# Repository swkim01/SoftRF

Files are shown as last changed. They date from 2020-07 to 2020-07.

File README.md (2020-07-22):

# SoftRF &nbsp;&nbsp;&nbsp;&nbsp;&nbsp;   
Multifunctional DIY IoT-based general aviation proximity awareness system.

Features:
* 2-way raw data bridge between 868/915 MHz radio band and Wi-Fi ;
* standalone, battery powered, compatible proximity awareness instrument that fits typical 2.25 inches hole ;
* lightweight version to carry onboard of an UAV.

# Compatibility <sup>1</sup>
Type|Protocol|FLARM|OGN tracker|PilotAware|Skytraxx|SoftRF
---|---|---|---|---|---|---
Radio|FLARM AIR V6||||<p align="center"><sup>2</sup></p>|
&nbsp;|<p align="center">OGNTP</p>|||||<p align="center"><sup>3</sup></p>
&nbsp;|<p align="center">P3I</p>|||||<p align="center"><sup>3</sup></p>
&nbsp;|<p align="center">UAT&nbsp;978</p>|||||<p align="center"><sup>4</sup></p>
&nbsp;|<p align="center">FANET+</p>|||||<p align="center"><sup>3</sup></p>
Data|FLARM NMEA|||||
&nbsp;|Garmin GDL90|||||
&nbsp;|<p align="center">MAVLINK</p>|||||
&nbsp;|<p align="center">Dump1090 &nbsp;<sup>5</sup></p>|||||

<sup>1</sup> - it is necessary for a reader to distinguish the difference between statement "**compatible**" and statement "**fully compatible**".<br>
&nbsp;&nbsp;&nbsp;&nbsp; SoftRF implements only a reasonable minimum of the protocols specs. No "bells and whistles" so far.<br>
<sup>2</sup> - FANET+ can not receive FLARM. However it is able to transmit it.<br>
<sup>3</sup> - valid for [**Prime Mark II**](https://github.com/lyusupov/SoftRF/wiki/Prime-Edition-MkII) and [**Dongle**](https://github.com/lyusupov/SoftRF/wiki/Dongle-Edition) **Editions**; valid for **Standalone** and **UAV** **Editions** with optional DIY [SoftRF LoRa RF module](https://github.com/lyusupov/SoftRF/wiki/SoftRF-LoRa-module)<br>
<sup>4</sup> - [**Reception**](https://github.com/lyusupov/SoftRF/tree/master/software/firmware/source/UATbridge) of traffic 'downlink' frames only. Valid for **Standalone Edition** with optional DIY [SoftRF UAT module](https://github.com/lyusupov/UAT-test-signal#variant-2-advanced)<br>
<sup>5</sup> - also known as "raw ADS-B"<br>

# Models
Model|Platform|First appearance|&nbsp;&nbsp;&nbsp;&nbsp;&nbsp;&nbsp;&nbsp;Status&nbsp;&nbsp;&nbsp;&nbsp;&nbsp;&nbsp;&nbsp;|Comment
---|:---:|:---:|:---:|---
1&nbsp;[Prime](https://github.com/lyusupov/SoftRF/wiki/Prime-Edition)<br>2&nbsp;[Standalone](https://github.com/lyusupov/SoftRF/wiki/Standalone-Edition)<br>3&nbsp;[UAV](https://github.com/lyusupov/SoftRF/wiki/UAV-Edition)<br>4&nbsp;[**WebTop**](https://github.com/lyusupov/SoftRF/wiki/WebTop-WiFi-adapter)|[Espressif<br>ESP8266](https://en.wikipedia.org/wiki/ESP8266)|Q4 2015||[Prime](https://github.com/lyusupov/SoftRF/wiki/Prime-Edition) model is no longer supported - use [Prime MkII](https://github.com/lyusupov/SoftRF/wiki/Prime-Edition-MkII) instead.<br><!-- ESP8266 platform will be phased out through year 2020 in favour of ESP32.-->
1&nbsp;[**Prime Mark II**](https://github.com/lyusupov/SoftRF/wiki/Prime-Edition-MkII)<br>2&nbsp;[**Standalone**](https://github.com/lyusupov/SoftRF/wiki/Standalone-Edition) + [adapter](https://github.com/lyusupov/ESP32-NODEMCU-ADAPTER)<br>3&nbsp;[UAV](https://github.com/lyusupov/SoftRF/wiki/UAV-Edition)<br>4&nbsp;[**SkyView EZ**](https://github.com/lyusupov/SoftRF/wiki/SkyView-EZ)<br>5&nbsp;[Flight Recorder](https://github.com/lyusupov/SoftRF/wiki/Flight-Recorder)|[Espressif<br>ESP32](https://en.wikipedia.org/wiki/ESP32)|Q1 2018||Today's best platform
1&nbsp;[**Raspberry Edition**](https://github.com/lyusupov/SoftRF/wiki/Raspberry-Edition)<br>2&nbsp;[**SkyView Pi**](https://github.com/lyusupov/SoftRF/wiki/SkyView-Pi)|[Broadcom<br>BCM283X<br>(Raspberry Pi)](https://en.wikipedia.org/wiki/Raspberry_Pi)|Q4 2018||Good for use together with RTL-SDR dongles to achieve additional 1090ES (and 978UAT) ADS-B air traffic reception.
1&nbsp;[UAT module](https://github.com/lyusupov/UAT-test-signal#variant-2-advanced)<br>2&nbsp;**Uni**|[Texas Instruments<br>CC1310](http://www.ti.com/product/CC1310) and [CC1352](http://www.ti.com/product/CC1352R)|Q1 2019|<!-- ![](https://placehold.it/140x40/c5f015/000000?text=May+need)<br>![](https://placehold.it/140x40/c5f015/000000?text=improvements) --> <!-- ![](https://placehold.it/140x70/FFFF00/000000?text=In+progress) -->|Unique RF radio specs are useful for [UAT reception](https://github.com/lyusupov/SoftRF/tree/master/software/firmware/source/UATbridge) [ [1](https://raw.githubusercontent.com/lyusupov/SoftRF/master/documents/images/uat-normal-7.jpg) , [2](https://raw.githubusercontent.com/lyusupov/SoftRF/master/documents/images/uat-normal-8.jpg) , [3](https://raw.githubusercontent.com/lyusupov/SoftRF/master/documents/images/uat-normal-6.jpg) ].
1&nbsp;[**Dongle**](https://github.com/lyusupov/SoftRF/wiki/Dongle-Edition)<br>2&nbsp;[Retro](https://github.com/lyusupov/SoftRF/wiki/Retro-Edition)|[STMicroelectronics<br>STM32](https://en.wikipedia.org/wiki/STM32)|Q3 2019|<!-- ![](https://placehold.it/140x70/FFFF00/000000?text=In+progress)-->|[AcSiP **S76G**](http://www.acsip.com.tw/index.php?action=products-detail&fid1=19&fid2=&fid3=&id=41&lang=3) "3-in-1" system-in-package **is doing good** [ [1](https://raw.githubusercontent.com/lyusupov/SoftRF/master/documents/images/watch-1.jpg) , [2](https://raw.githubusercontent.com/lyusupov/SoftRF/master/documents/images/t-motion-4.jpg) , [3](https://raw.githubusercontent.com/lyusupov/SoftRF/master/documents/images/t-motion-5.jpg) ] .<br>As well as STM32F103C8 "**Blue Pill**" (same MCU that [STM32 OGN tracker](http://wiki.glidernet.org/stm32-ogn-tracker) uses) [ [4](https://raw.githubusercontent.com/lyusupov/SoftRF/master/documents/images/stm32_breadboard.jpg) , [5](https://raw.githubusercontent.com/lyusupov/SoftRF/master/documents/images/stm32_ognweb_1.JPG) ] .

# Documentation

* SoftRF overview
    * [Part 1](https://github.com/lyusupov/SoftRF/blob/master/documents/SoftRF-release-1.pdf) (PDF, December 2015)
    * [Part 2](https://github.com/lyusupov/SoftRF/raw/master/documents/SoftRF-release-2.pdf) (PDF, March 2017)
* [Prime Edition MkII](https://github.com/lyusupov/SoftRF/wiki/Prime-Edition-MkII) 
    * [Quick start](https://github.com/lyusupov/SoftRF/wiki/Prime-Edition-MkII.-Quick-start)
    * [Enclosure](https://github.com/lyusupov/SoftRF/tree/master/case/v5)
* [Standalone Edition](https://github.com/lyusupov/SoftRF/wiki/Standalone-Edition)
    * [Specifications](https://github.com/lyusupov/SoftRF/wiki/Standalone-Specifications)
    * [Shield](https://github.com/lyusupov/SoftRF/wiki/Standalone-Shield)
    * [Modules](https://github.com/lyusupov/SoftRF/wiki/Standalone-Modules)
    * [Assembly](https://github.com/lyusupov/SoftRF/tree/master/hardware)
    * [Enclosure](https://github.com/lyusupov/SoftRF/tree/master/case/v4)
    * [ESP32 adapter](https://github.com/lyusupov/ESP32-NODEMCU-ADAPTER)
* [Dongle Edition](https://github.com/lyusupov/SoftRF/wiki/Dongle-Edition) 
    * [Firmware installation](https://github.com/lyusupov/SoftRF/wiki/AcSiP-S7xG-flashing-instructions)
    * [Quick start](https://github.com/lyusupov/SoftRF/wiki/Dongle-Edition.-Quick-start)
    * [Settings](https://github.com/lyusupov/SoftRF/wiki/Dongle-settings)
    * [Enclosure](https://github.com/lyusupov/SoftRF/tree/master/case/Dongle)
* [UAV Edition](https://github.com/lyusupov/SoftRF/wiki/UAV-Edition)
    * [Bill of materials](https://github.com/lyusupov/SoftRF/wiki/UAV-BOM)
    * [Wiring and pin-out](https://github.com/lyusupov/ESP32-NODEMCU-ADAPTER)
    * [Enclosure](https://github.com/lyusupov/SoftRF/tree/master/case/UAV)
* [Raspberry Edition](https://github.com/lyusupov/SoftRF/wiki/Raspberry-Edition) 
* [Retro Edition](https://github.com/lyusupov/SoftRF/wiki/Retro-Edition)

* SkyView
    * [EZ](https://github.com/lyusupov/SoftRF/wiki/SkyView-EZ) 
        * [Quick start](https://github.com/lyusupov/SoftRF/wiki/SkyView.-Quick-start)
        * [Settings](https://github.com/lyusupov/SoftRF/wiki/SkyView-settings)
        * [Enclosure](https://github.com/lyusupov/SoftRF/tree/master/case/SkyView)
        * [Dual boot](https://github.com/lyusupov/SoftRF/wiki/SkyView.-Dual-boot) 
    * [Pi](https://github.com/lyusupov/SoftRF/wiki/SkyView-Pi) 
* [WebTop](https://github.com/lyusupov/SoftRF/wiki/WebTop-WiFi-adapter) 

* [Flight Recorder](https://github.com/lyusupov/SoftRF/wiki/Flight-Recorder)
    * [Quick start](https://github.com/lyusupov/SoftRF/wiki/Flight-Recorder.-Quick-Start)

* Software
    * Firmware
        * [Release information](https://github.com/lyusupov/SoftRF/releases) 
        * [Binary](https://github.com/lyusupov/SoftRF/tree/master/software/firmware/binaries)
        * [Settings](https://github.com/lyusupov/SoftRF/wiki/Settings)
        * [Update](https://github.com/lyusupov/SoftRF/wiki/Firmware-update-(Web-method)) (Web method)
        * [Source](https://github.com/lyusupov/SoftRF/tree/master/software/firmware/source)
* Extras
    * [Long range (LoRa) RF module](https://github.com/lyusupov/SoftRF/wiki/SoftRF-LoRa-module)
    * Protocols
        * [UAT](https://github.com/lyusupov/SoftRF/tree/master/software/firmware/source/UATbridge)    
        * [OGNTP](https://github.com/lyusupov/SoftRF/wiki/OGNTP-compatibility)
        * [P3I Open (PilotAware)](https://github.com/lyusupov/SoftRF/wiki/PilotAware-compatibility)
        * [FANET (Skytraxx)](https://github.com/lyusupov/SoftRF/wiki/FANET-compatibility)
    * [Garmin GDL90 datalink](https://github.com/lyusupov/SoftRF/wiki/Garmin-GDL90-compatibility)
        * [SkyDemon](https://github.com/lyusupov/SoftRF/wiki/Garmin-GDL90-compatibility#skydemon)
        * [Avare](https://github.com/lyusupov/SoftRF/wiki/Garmin-GDL90-compatibility#avare)
        * [ForeFlight](https://github.com/lyusupov/SoftRF/wiki/Garmin-GDL90-compatibility#foreflight)
    * [Integration with airborne (Stratux, PilotAware,...) and groundstation (FlightRadar24, FlightAware,...) ADS-B receivers](https://github.com/lyusupov/SoftRF/wiki/Integration-with-RTL%E2%80%90SDR-based-ADS%E2%80%90B-receivers)
    * [Combined use of multiple SoftRF units](https://github.com/lyusupov/SoftRF/tree/master/software/app/XCSoar7_preview12_plus)
* Archive
    * [Prime Edition](https://github.com/lyusupov/SoftRF/wiki/Prime-Edition)
        * [Bill of materials](https://github.com/lyusupov/SoftRF/wiki/Prime-BOM)
        * [Wiring](https://github.com/lyusupov/SoftRF/wiki/Prime-Wiring)
        * [Enclosure](https://github.com/lyusupov/SoftRF/tree/master/case/v1)
    * Applications
        * [Emulator](https://github.com/lyusupov/SoftRF/tree/master/software/app/Emulator)

# Highlights

* [**Prime Edition Mark II**](https://github.com/lyusupov/SoftRF/wiki/Prime-Edition-MkII)



* [**Standalone Edition**](https://github.com/lyusupov/SoftRF/wiki/Standalone-Edition)





* [**Dongle Edition**](https://github.com/lyusupov/SoftRF/wiki/Dongle-Edition)

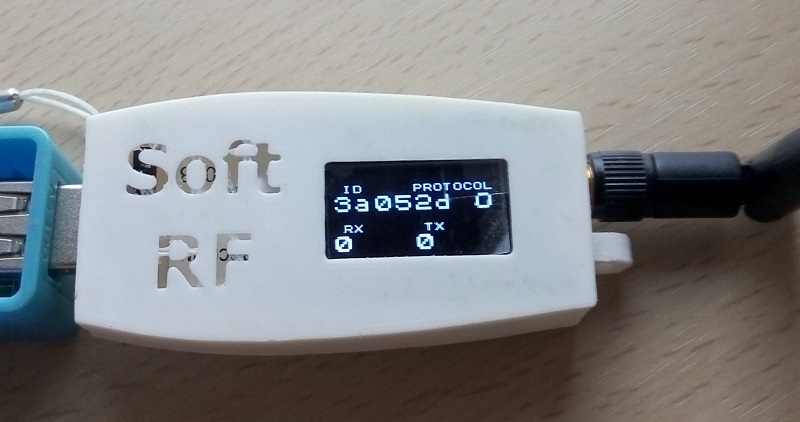
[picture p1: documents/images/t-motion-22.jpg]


* [**SkyView EZ**](https://github.com/lyusupov/SoftRF/wiki/SkyView-EZ)



* [**UAV appliance**](https://github.com/lyusupov/SoftRF/wiki/UAV-Edition)



* [**Flight Recorder**](https://github.com/lyusupov/SoftRF/wiki/Flight-Recorder)

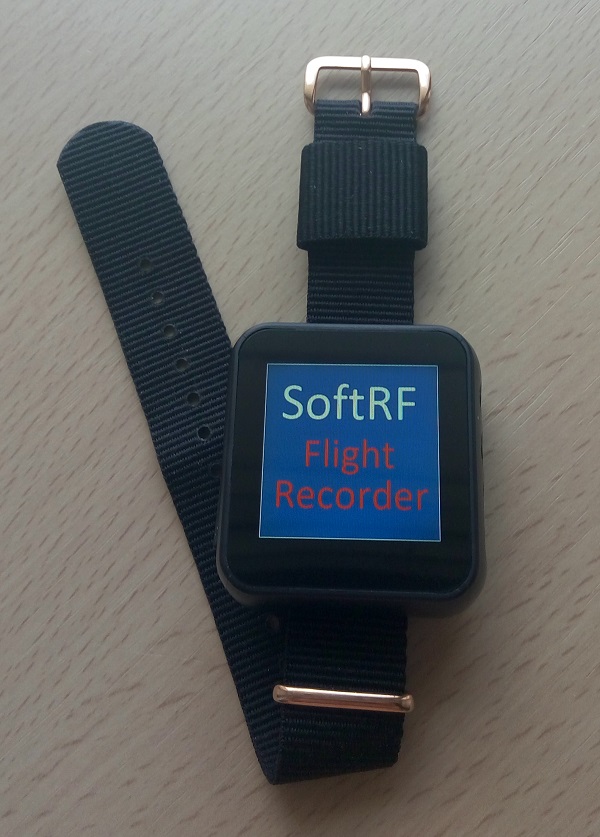
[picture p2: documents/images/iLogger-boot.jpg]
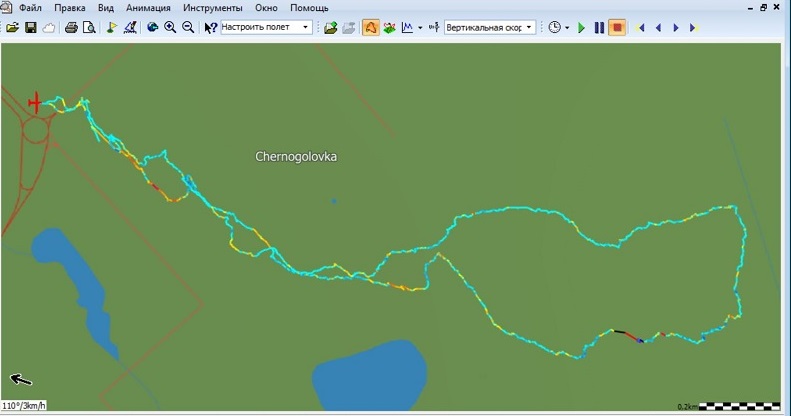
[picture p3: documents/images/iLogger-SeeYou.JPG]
<p>&nbsp;</p>

<!--
* [**Software driven emulation**](https://github.com/lyusupov/SoftRF/wiki/Prime-Edition)

![](https://github.com/lyusupov/SoftRF/raw/master/documents/images/softrf-emulation.jpg)

![](https://github.com/lyusupov/SoftRF/raw/master/documents/images/LK8000-emu.jpg)

![](https://github.com/lyusupov/SoftRF/blob/master/case/v1/SoftRF-Case-v1-Exterior.jpg)
-->

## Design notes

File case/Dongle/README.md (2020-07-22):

# Dongle enclosure 

This type of enclosure is built around LilyGO&#174; & SoftRF [**T-Motion**](https://github.com/lyusupov/SoftRF/wiki/Dongle-Edition#required) LoRaWAN GNSS tracker board.<br>

**NOTICE**: This design is applicable for revision V1.1 (pre-production sample) of the T-Motion. Other revisions may or may not match.

# Exterior

It is recommended to start with 'Slim' variant of the design.<br>
It has almost no space for 'extras'. However it gives an access to the board pin headers and BOOT button.<br>

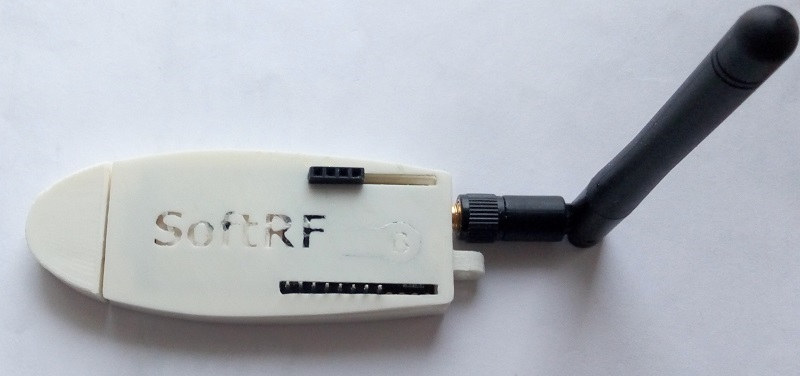
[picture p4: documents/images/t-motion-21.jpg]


<br>

There is an alternative design for the lid of this enclosure to fit for [0.96" OLED I<sup>2</sup>C display](https://www.aliexpress.com/item/32922106384.html)<br>



<br>

and an alternative design for main 'body' to give some space for:

- [402030 Li-Ion battery](https://www.aliexpress.com/item/32909694329.html) and/or
- [I<sup>2</sup>C BMP280 barometric pressure sensor](https://www.aliexpress.com/item/32680504702.html).

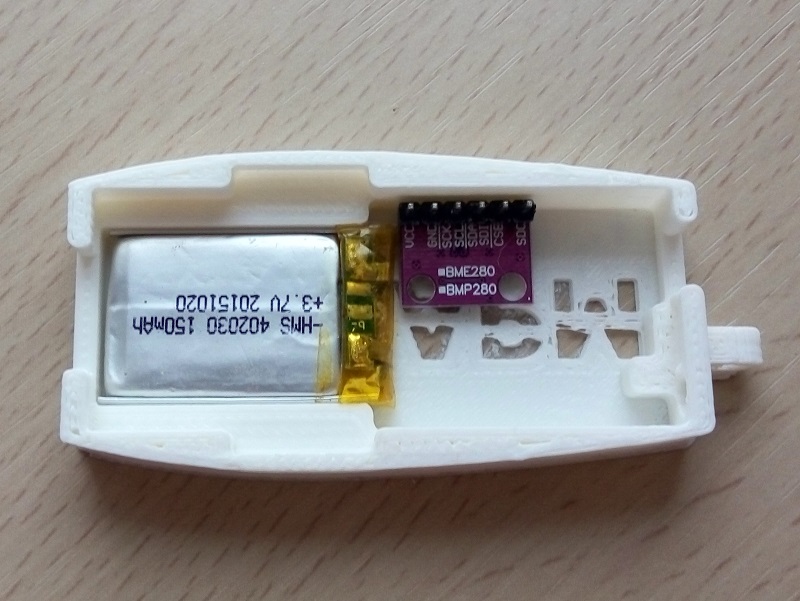
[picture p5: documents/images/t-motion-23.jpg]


<br>

# Instructions

3D print three STL files from this folder: **Body**, **Lid** and **Cap**. You may pick some printing advisories on [my Thingiverse page](https://www.thingiverse.com/thing:4033445).<br>
If you are unable to print the parts by yourself - you may consider to find an appropriate local 3D service provider and place an order with assistance of [Treatstock](http://www.treatstock.com) or [3DHubs](http://www.3dhubs.com/) portals.

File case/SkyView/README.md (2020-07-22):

# SkyView enclosure 

This type of enclosure is built around [TTGO T5S](http://s.click.aliexpress.com/e/Zp4ygfQ) board.<br>

**NOTICE**: This design is applicable for revision V1.9 of T5S. Other revisions may not match.

# Exterior

<p>
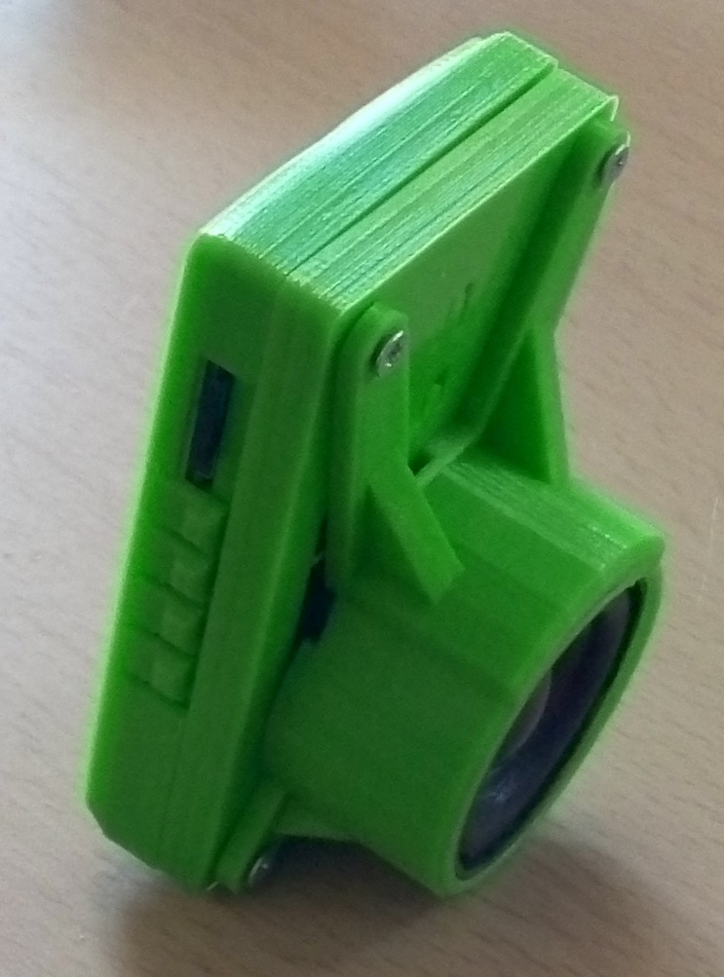
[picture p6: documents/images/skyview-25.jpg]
&nbsp;
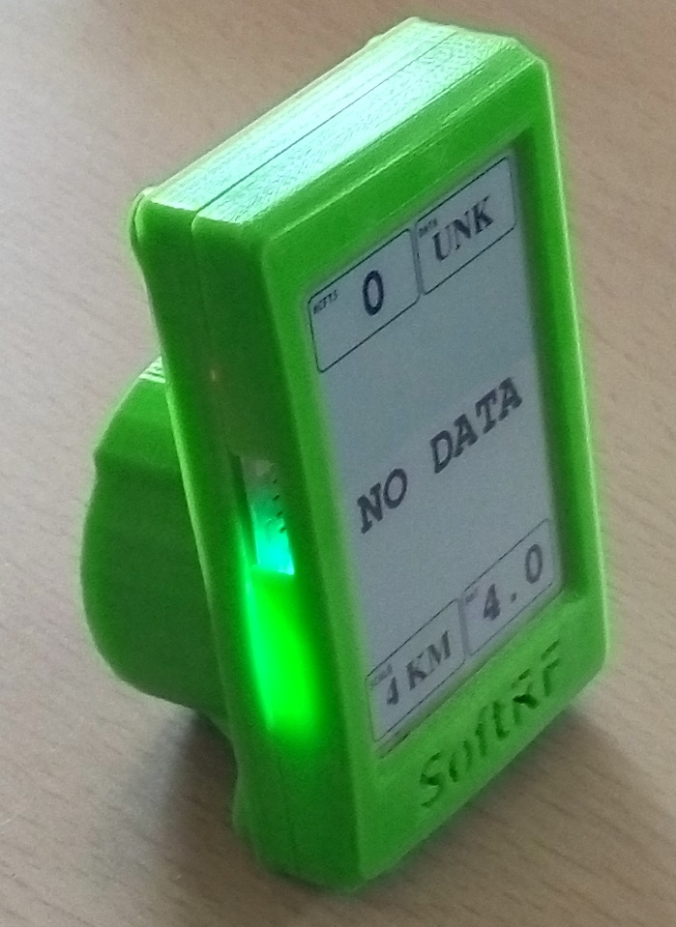
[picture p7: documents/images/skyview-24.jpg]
&nbsp;</p>

<br>

# Components



<br>

# Instructions

Choose an appropriate **Body** STL file based upon your measured battery dimensions:
* **Body** is to fit for reference 62x35x6 mm battery, or
* **Body-plus** - it has +1 mm increase for height and width of battery compartment.

3D print two STL files from this folder: **Body**(-plus) and **Face**. You may pick some printing advisories on [my Thingiverse page](http://www.thingiverse.com/thing:3702447).<br>
If you are unable to print the parts by yourself - you may consider to find an appropriate local 3D service provider and place an order with assistance of [Treatstock](http://www.treatstock.com) or [3DHubs](http://www.3dhubs.com/) portals.

Fasten the T5S board to the enclosure's main body with four 2.5x10 mm screws.
Put face plate on top of the assembly.

# Speaker mount option

3D print **Speaker** STL file from this folder.<br>

Put 40 mm speaker inside the printed mount.<br>
Fasten the mount to the enclosure's main body with four 2.5x8 mm screws.

<br>

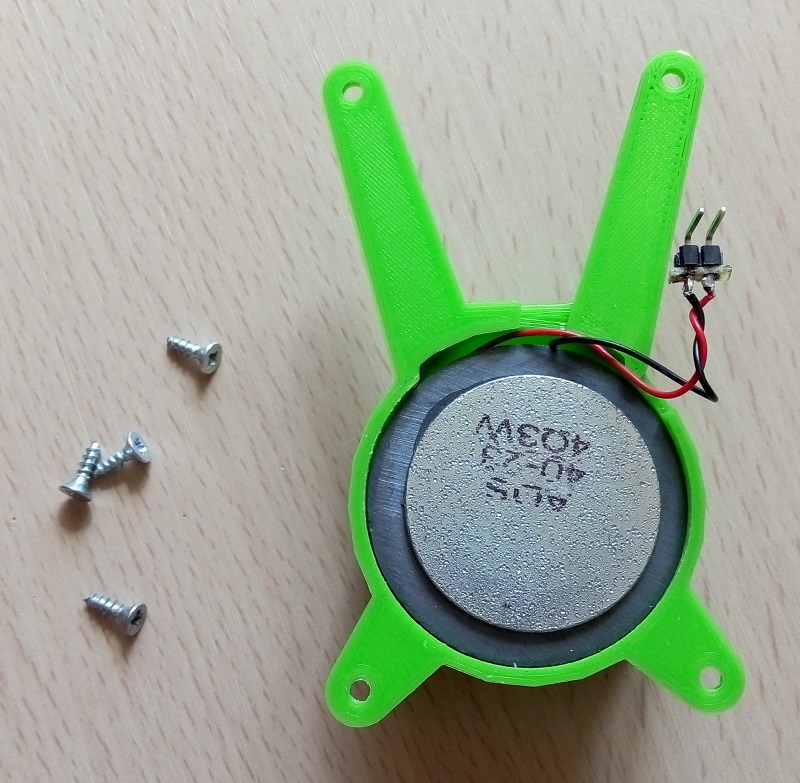
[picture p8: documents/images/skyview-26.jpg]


<br>

# Holder

<br>

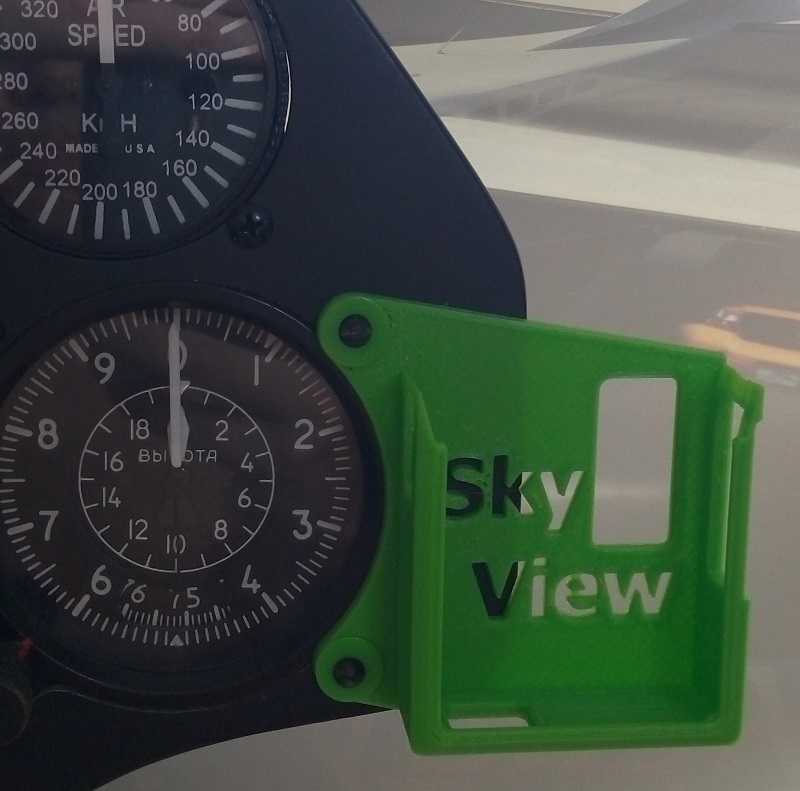
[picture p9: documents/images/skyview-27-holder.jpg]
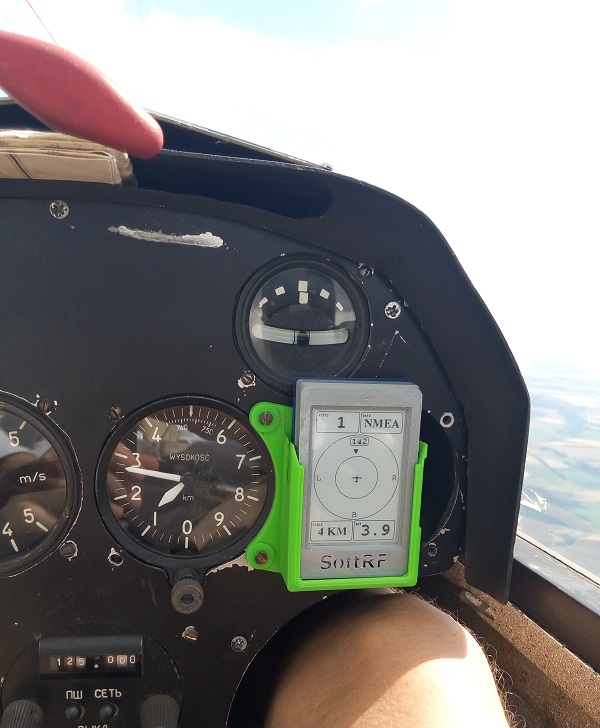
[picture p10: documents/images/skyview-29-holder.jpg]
<p>&nbsp;&nbsp;&nbsp;</p>

<br>

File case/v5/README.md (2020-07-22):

# Enclosure version 5.0

This type of enclosure is built around [TTGO T-Beam](https://www.aliexpress.com/store/product/TTGO-T-Beam-ESP32-Wi-Fi-Bluetooth-ESP-32-gps-NEO/2090076_32875743018.html) LoRaWAN GNSS tracker board.

# Exterior



# Components



# Instructions

3D print three STL files from this folder: **Body**, **Lid** and **Face**. You may pick some printing advisories on [my Thingiverse page](http://www.thingiverse.com/thing:3041339).<br>
Files that have:
* no suffix are either universal or best suited for older **V02-V07** revisions of the TTGO T-Beam board ;
* **-V08** suffix are best suited for revisions **V08** (20190423) and **V10** (20190612) of the T-Beam ;
* **-V11** suffix are best suited for most recent **V11** (20191212) revision of this board ;

If you are unable to print the parts by yourself - you may consider to find an appropriate local 3D service provider and place an order with assistance of [Treatstock](http://www.treatstock.com) or [3DHubs](http://www.3dhubs.com/) portals.

At first, insert printed face panel into front rails. Place T-Beam board into the enclosure's main body. Put lid on top of the assembly. Fasten the lid with four 2.5x10 mm screws.

# Options

## GoPro mount

Two variants of main body are available. One is with GoPro mount and another one is without it.



<br>

## Antenna protector

If you, by any reason, keep using your small T-Beam 'stock' 868 MHz antenna - you may think about to 3D print an alternative lid that has a cone 'bumper'.<br>
This little 'feature' may help for the antenna to survive if the device will experience an upside down free fall.<br> 
And it looks nicer, isn't it?

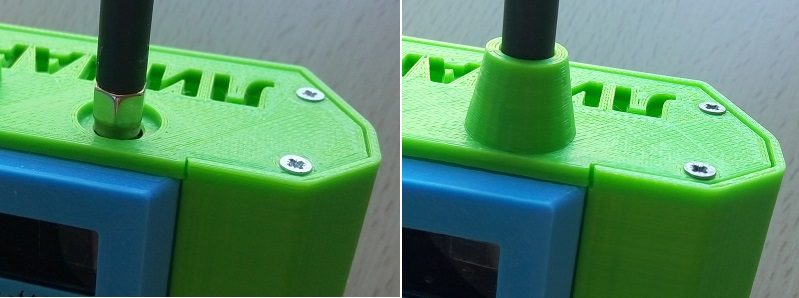
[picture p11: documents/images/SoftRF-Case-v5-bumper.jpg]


<br>

## OLED display

You may opt for 0.96" front I2C OLED display panel.<br>
Be aware that average 0.96" OLED does not perform well against sun light.<br>
Two variants of the panel are available: 
- the first design is for generic 0.96" OLED ;
- the other one is for [TTGO version](https://www.aliexpress.com/item/32922106384.html) of the display.



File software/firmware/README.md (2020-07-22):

## WebUI



## License

Copyright (C) 2016-2020 Linar Yusupov <linar.r.yusupov@gmail.com>

This program is free software: you can redistribute it and/or modify
it under the terms of the GNU General Public License as published by
the Free Software Foundation, either version 3 of the License, or
(at your option) any later version.

This program is distributed in the hope that it will be useful,
but WITHOUT ANY WARRANTY; without even the implied warranty of
MERCHANTABILITY or FITNESS FOR A PARTICULAR PURPOSE.  See the
GNU General Public License for more details.

You should have received a copy of the GNU General Public License
along with this program.  If not, see <http://www.gnu.org/licenses/>.

## Credits

 * Arduino core for ESP8266 is developed/supported by **ESP8266 Community** (support-esp8266@esp8266.com)
 * AVR/Arduino nRF905 Library/Driver is developed by **Zak Kemble**, contact@zakkemble.co.uk
 * flarm_decode is developed by **Stanislaw Pusep**, http://github.com/creaktive
 * Arduino Time Library is developed by **Paul Stoffregen**, http://github.com/PaulStoffregen
 * "Aircraft" and MAVLink Libraries are developed by **Andy Little**
 * TinyGPS++ and PString Libraries are developed by **Mikal Hart**
 * Adafruit NeoPixel Library is developed by **Phil Burgess**, **Michael Miller** and others
 * TrueRandom Library is developed by **Peter Knight**
 * IBM LMIC framework is maintained by **Matthijs Kooijman**
 * ESP8266FtpServer is developed by **David Paiva**
 * Lib_crc is developed by **Lammert Bies**
 * OGN library is developed by **Pawel Jalocha**
 * NMEA library is developed by **Timur Sinitsyn**, **Tobias Simon**, **Ferry Huberts**
 * ADS-B encoder C++ library is developed by **yangbinbin** (yangbinbin_ytu@163.com)
 * Arduino Core for ESP32 is developed by **Hristo Gochkov**
 * Adafruit BMP085 library is developed by **Limor Fried** and **Ladyada**
 * Adafruit BMP280 library is developed by **Kevin Townsend**
 * Adafruit MPL3115A2 library is developed by **Limor Fried** and **Kevin Townsend**
 * U8g2 monochrome LCD, OLED and eInk library is developed by **Oliver Kraus**
 * NeoPixelBus library is developed by **Michael Miller**
 * jQuery library is developed by **JS Foundation**
 * EGM96 data is developed by **XCSoar team**
 * BCM2835 C library is developed by **Mike McCauley**
 * SimpleNetwork library is developed by **Dario Longobardi**
 * ArduinoJson library is developed by **Benoit Blanchon**
 * Flashrom library is part of the **flashrom.org project**
 * Arduino Core for TI CC13X0 is developed by **Energia team**
 * EasyLink library is developed by **Robert Wessels** and **Tony Cave**
 * Dump978 library is developed by **Oliver Jowett**
 * FEC library is developed by **Phil Karn**
 * AXP20X, BMA423, FT5206 and PCF8563 libraries are developed by **Lewis He**
 * GxEPD2 library is developed by **Jean-Marc Zingg**
 * Adafruit SSD1306 and GFX libraries are developed by **Adafruit Industries**
 * GDL90 decoder is developed by **Ryan David**
 * Sqlite3 Arduino library for ESP32 is developed by **Arundale Ramanathan**
 * FLN/OGN aircrafts data is courtesy of **FlarmNet/GliderNet**
 * ESP32 I2S WAV player example is developed by **Tuan Nha**
 * AceButton library is developed by **Brian Park**
 * Arduino Core for STM32 is developed by **Frederic Pillon**
 * Python IGC format encoder is developed by **Tobias Bieniek**
 * port of MicroPython for ESP32 is developed by **Boris Lovosevic**
 * ESP32 BT SPP library is developed by **Evandro Copercini**
 * TFT library is developed by **Bodmer**

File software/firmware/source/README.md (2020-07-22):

# SoftRF firmware build instructions

[NodeMCU](https://github.com/lyusupov/SoftRF/tree/master/software/firmware/source#nodemcu)<br>
[ESP32](https://github.com/lyusupov/SoftRF/tree/master/software/firmware/source#esp32)<br>
[Raspberry Pi](https://github.com/lyusupov/SoftRF/tree/master/software/firmware/source#raspberry-pi)<br>
[CC13XX](https://github.com/lyusupov/SoftRF/tree/master/software/firmware/source#cc13xx)<br>
[STM32](https://github.com/lyusupov/SoftRF/tree/master/software/firmware/source#stm32)<br>

<br>

## NodeMCU

1. Follow [these official instructions](https://github.com/esp8266/Arduino#installing-with-boards-manager)
  to install Arduino IDE and latest Arduino ESP8266 Core
2. Become familiar with IDE and **NodeMCU** by building and uploading of a basic **Blink** sketch:<br>

    _File_ -> _Examples_ -> _ESP8266_ -> _Blink_ <br>

    then<br>

    _Sketch_ -> _Upload_

3. When you are done with the lesson, close your **Arduino** application
4. open ``<My Documents>`` (Windows) or ``<Home>`` (Linux) directory
5. create **Arduino** sub-directory
6. transfer full content of **SoftRF** and **libraries** GitHub folders into the sub-directory:

    [SoftRF](https://github.com/lyusupov/SoftRF/tree/master/software/firmware/source/SoftRF) &nbsp;&nbsp;**-->** ``<My Documents>``/Arduino/SoftRF <br>
    [libraries](https://github.com/lyusupov/SoftRF/tree/master/software/firmware/source/libraries) **-->** ``<My Documents>``/Arduino/libraries <br>

7. start **Arduino** application again
8. open **SoftRF** sketch from _File_ -> _Open_ menu
9. Select _Tools_ -> _Board_ -> _NodeMCU_ _1.0_
10. in _Tools_ -> _lwIP Variant_  -> _v2 Higher Bandwidth_
11. _Sketch_ -> _Upload_

## ESP32

1. Follow [these official instructions](https://github.com/espressif/arduino-esp32/blob/master/docs/arduino-ide/boards_manager.md)
  to install Arduino IDE and [latest **stable** Arduino ESP32 Core](https://github.com/espressif/arduino-esp32/releases/tag/1.0.4) (1.0.4)
2. Become familiar with IDE and **DoIt ESP32 DevKit** by building and uploading of a basic **Blink** sketch:<br>
```
int ledPin = 2; // use pin 14 for TTGO T-Beam rev.05 or higher   

void setup()
{
    pinMode(ledPin, OUTPUT);
    Serial.begin(115200);
}

void loop()
{
    Serial.println("Hello, world!");
    digitalWrite(ledPin, HIGH);
    delay(500);
    digitalWrite(ledPin, LOW);
    delay(500);
}
```

3. When you are done with the lesson, close your **Arduino** application
4. open ``<My Documents>`` (Windows) or ``<Home>`` (Linux) directory
5. create **Arduino** sub-directory
6. transfer full content of **SoftRF** and **libraries** GitHub folders into the sub-directory:

    [SoftRF](https://github.com/lyusupov/SoftRF/tree/master/software/firmware/source/SoftRF) &nbsp;&nbsp;**-->** ``<My Documents>``/Arduino/SoftRF <br>
    [libraries](https://github.com/lyusupov/SoftRF/tree/master/software/firmware/source/libraries) **-->** ``<My Documents>``/Arduino/libraries <br>

7. start **Arduino** application again
8. open **SoftRF** sketch from _File_ -> _Open_ menu
9. Select _Tools_ -> _Board_ ->  _ESP32_ _Dev_ _Module_
10. Select _Tools_ -> _Flash_ _Mode_ ->  _DIO_
11. Select _Tools_ -> _Flash_ _Size_ ->  _4MB_
12. Select _Tools_ -> _Partition_ _Scheme_ ->  _Minimal_ _SPIFFS_
13. Select _Tools_ -> _Flash_ _Frequency_ ->  _80MHz_
14. Select _Tools_ -> _CPU_ _Frequency_ ->  _80MHz_
15. Select _Tools_ -> _PSRAM_ ->  _Enabled_
16. _Sketch_ -> _Upload_

<br>

## Raspberry Pi

Although CLI application's source code for Raspberry Edition is located [at the same place](https://github.com/lyusupov/SoftRF/tree/master/software/firmware/source)<br> 
and is shared with other SoftRF platforms - build instructions for the code are different.

This build has to be done on a Raspberry Pi host.<br>
A known good Raspbian OS version that fits for this purpose is "Stretch".<br>
Make sure that basic development packages (such as: binutils, g++, GNU make & etc) are installed.<br>

1. transfer full content of **SoftRF** and **libraries** GitHub folders into a temporary build directory:

    [SoftRF](https://github.com/lyusupov/SoftRF/tree/master/software/firmware/source/SoftRF) &nbsp;&nbsp;**-->** ``<your path>``/SoftRF <br>
    [libraries](https://github.com/lyusupov/SoftRF/tree/master/software/firmware/source/libraries) **-->** ``<your path>``/libraries <br>

2. change directory on ``<your path>``/SoftRF and execute **make** as follows:<br>

```
pi@raspberrypi: $ make pi
(cd ../libraries/bcm2835/src/../ ; ./configure ; make)
checking for a BSD-compatible install... /usr/bin/install -c
checking whether build environment is sane... yes
checking for a thread-safe mkdir -p... /bin/mkdir -p
checking for gawk... no

< ... skipped ... >
```

As a result of the build, two program binaries will become created:
- **SoftRF** - the program code designed to work with Raspberry Pi's primary SPI bus (SPI 0);
- **SoftRF-aux** - the same program but to run over auxiliary SPI bus (SPI 1).

<br>

## CC13XX

[Energia](http://energia.nu/download/) IDE has to be pre-installed first.<br>

1. open ``<Home>`` directory
2. create **Energia** sub-directory
3. transfer full content of **SoftRF** and **libraries** GitHub folders into the sub-directory:

    [SoftRF](https://github.com/lyusupov/SoftRF/tree/master/software/firmware/source/SoftRF) &nbsp;&nbsp;**-->** ``<My Documents>``/Energia/SoftRF <br>
    [libraries](https://github.com/lyusupov/SoftRF/tree/master/software/firmware/source/libraries) **-->** ``<My Documents>``/Energia/libraries <br>

4. start **Energia** application
5. open **SoftRF** sketch from _File_ -> _Open_ menu
6. [install support](http://energia.nu/guide/boards/) for TI CC13XX familiy with _Tools_ -> _Board_ ->  _Boards_ _Manager..._
7. Select _Tools_ -> _Board_ ->  _LaunchPad_ _w/_ _CC1310_ _EMT_ _(48MHz)_
8. Select _Tools_ -> _Port_ ->  ``<your XDS110 port device name>``
9. Select _Tools_ -> _Programmer_ ->  _dslite_
10. try to build and upload using _Sketch_ -> _Upload_

10a. or, to build the firmware using shell prompt, do:

```
$ make build
energia --verify --verbose-build SoftRF.ino
Picked up JAVA_TOOL_OPTIONS:
Loading configuration...
Initializing packages...
Preparing boards...
Verifying...

< ... skipped ... >
```

11a. inspect **/tmp** directory and sub-folders, take **SoftRF.ino.elf** file and use it with TI's **Uniflash** or **Flash Programmer 2**.<br>

12a. (Optional) if you want to use [**cc2538-bsl.py**](https://github.com/JelmerT/cc2538-bsl) tool to put the firmware into flash memory of CC1310 IC via **boot loader**, run **make ihex**:

```
$ make ihex

< ... skipped ... >
``` 

<br>

## STM32

You will also need to get and connect ST-LINK/V2 USB adapter in order to put the firmware into your hardware's flash memory.<br>

1. Follow [these official instructions](https://github.com/stm32duino/wiki/wiki/Getting-Started)
  to install Arduino IDE and [latest **stable** Arduino STM32 Core](https://github.com/stm32duino/Arduino_Core_STM32/releases/tag/1.9.0) (1.9.0)
2. open ``<My Documents>`` (Windows) or ``<Home>`` (Linux) directory
3. create **Arduino** sub-directory
4. transfer full content of **SoftRF** and **libraries** GitHub folders into the sub-directory:

    [SoftRF](https://github.com/lyusupov/SoftRF/tree/master/software/firmware/source/SoftRF) &nbsp;&nbsp;**-->** ``<My Documents>``/Arduino/SoftRF <br>
    [libraries](https://github.com/lyusupov/SoftRF/tree/master/software/firmware/source/libraries) **-->** ``<My Documents>``/Arduino/libraries <br>

5. start **Arduino** application
6. open **SoftRF** sketch from _File_ -> _Open_ menu
7. For S76G:<br>
    &nbsp;&nbsp;&nbsp;&nbsp;&nbsp;&nbsp;Select _Tools_ -> _Board_ ->  _Nucleo_64_<br>
    &nbsp;&nbsp;&nbsp;&nbsp;&nbsp;&nbsp;Select _Tools_ -> _Optimize_ ->  _Fast_ _(-O1)_<br>
    &nbsp;&nbsp;&nbsp;&nbsp;&nbsp;&nbsp;Select _Tools_ -> _Board_ _part_ _number_ ->  _Nucleo_ _L073RZ_<br>
    For STM32F103C8 "Blue Pill":<br>
    &nbsp;&nbsp;&nbsp;&nbsp;&nbsp;&nbsp;Select _Tools_ -> _Board_ ->  _Generic_ _STM32F1_ _series_<br>
    &nbsp;&nbsp;&nbsp;&nbsp;&nbsp;&nbsp;Select _Tools_ -> _Optimize_ ->  _Smallest_ _(-Os_ _default)_<br>
    &nbsp;&nbsp;&nbsp;&nbsp;&nbsp;&nbsp;Select _Tools_ -> _Board_ _part_ _number_ ->  _BluePill_ _F103CB_ _(or_ _C8_ _with_ _128k)_<br>
8. Select _Tools_ -> _C_ _Runtime_ _library_ ->  _Newlib_ _Nano_ _(default)_
9. Select _Tools_ -> _USB_ _speed_ _(if available)_ ->  _Low/Full_ _Speed_
10. For S76G "Dongle":<br>
    &nbsp;&nbsp;&nbsp;&nbsp;&nbsp;&nbsp;Select _Tools_ -> _USB_ _support_ _(if available)_ ->  _CDC_ _(generic_ _'Serial'_ _supersede_ _U(S)ART)_<br>
    &nbsp;&nbsp;&nbsp;&nbsp;&nbsp;&nbsp;Select _Tools_ -> _U(S)ART_ _support_ ->  _Enabled_ _(no_ _generic_ _'Serial')_<br>
    &nbsp;&nbsp;&nbsp;&nbsp;&nbsp;&nbsp;Select _Tools_ -> _Upload_ _method_ ->  _STM32CubeProgrammer_ _(DFU)_<br>
    &nbsp;&nbsp;&nbsp;&nbsp;&nbsp;&nbsp;Select _Tools_ -> _Port_ ->  ``<your Dongle's DFU device name>``<br>
    For S76G "SkyWatch" or STM32F103C8 "Blue Pill":<br>
    &nbsp;&nbsp;&nbsp;&nbsp;&nbsp;&nbsp;Select _Tools_ -> _USB_ _support_ _(if available)_ ->  _CDC_ _(no_ _generic_ _'Serial')_<br>
    &nbsp;&nbsp;&nbsp;&nbsp;&nbsp;&nbsp;Select _Tools_ -> _U(S)ART_ _support_ ->  _Enabled_ _(generic_ _'Serial')_<br>
    &nbsp;&nbsp;&nbsp;&nbsp;&nbsp;&nbsp;Select _Tools_ -> _Upload_ _method_ ->  _STM32CubeProgrammer_ _(SWD)_<br>
    &nbsp;&nbsp;&nbsp;&nbsp;&nbsp;&nbsp;Select _Tools_ -> _Port_ ->  ``<your ST-LINK/V2 port device name>``<br>
11. try to build and upload using _Sketch_ -> _Upload_

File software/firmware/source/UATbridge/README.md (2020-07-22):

## UAT Bridge

This folder contains source code of **UAT Bridge** firmware for Texas Instruments **CC1310** and **CC1352R** RF SoCs.<br>
The code is essential part of [SoftRF project](https://github.com/lyusupov/SoftRF).<br>

## Purpose

Primary purpose of the **UAT bridge** is to receive ADS-B traffic information on UAT (978 MHz) aviation frequency,<br>
then to re-broadcast the data using one of supported RF ISM band protocols.<br>

For the list of the ISM protocols, please, read [SoftRF specs](https://github.com/lyusupov/SoftRF#compatibility-1).<br>

Traffic information is re-broadcasted at very low power setting, so reception coverage is limited to a close vicinity of
the aircraft, equipped with the **UAT Bridge**. Other aircrafts nearby, such as gliders on the grid, have a chance to receive the information as well.<br>  

The "**bridge**" is one-way only. No re-broadcasting from ISM band into aviation band (UAT) is allowed. Thus, it does **not** transmit anything on 978 MHz.<br>

For the benefit of most of pilots, **receiving device is not necessarily has to be one of [SoftRF](https://github.com/lyusupov/SoftRF) units**.<br>
Other make and models, such as SkyTraxx, OGN Tracker, PilotAware or FLARM should suffice.<br> 

## Hardware

DIY **UAT bridge** hardware consists of:
1. [SoftRF-UAT](https://github.com/lyusupov/UAT-test-signal#variant-2-advanced) main board, and
2. [SoftRF-LoRa](https://github.com/lyusupov/SoftRF/wiki/SoftRF-LoRa-module) daughterboard.

<br>
<br>


## Alternative use

The firmware auto-senses presence of connected [SoftRF-LoRa](https://github.com/lyusupov/SoftRF/wiki/SoftRF-LoRa-module) daughterboard.<br>
When the daughterboard is not attached - remaining [SoftRF-UAT](https://github.com/lyusupov/UAT-test-signal#variant-2-advanced) board fallbacks into **UAT Receiver** operation mode automatically.<br>

**UAT Receiver** makes reception of UAT signals, then transmits serial data frames over UART @ 2 Mbps.<br>
This data rate and format of the frames were choosen to be compatible with [Stratux UATRadio, Low Power v3](https://www.amazon.com/dp/B07JNSHCLQ/).

## Build instructions

The firmware is to be built on a Linux x86_64 host.<br>
[Energia](http://energia.nu/download/) IDE has to be pre-installed first.<br>

1. open ``<Home>`` directory
2. create **Energia** sub-directory
3. transfer full content of **UATbridge**, **SoftRF** and **libraries** GitHub folders into the sub-directory:

    [UATbridge](https://github.com/lyusupov/SoftRF/tree/master/software/firmware/source/UATbridge) **-->** ``<Home>``/Energia/UATbridge <br>
    [SoftRF](https://github.com/lyusupov/SoftRF/tree/master/software/firmware/source/SoftRF) &nbsp;&nbsp;&nbsp;&nbsp;&nbsp;&nbsp;**-->** ``<Home>``/Energia/SoftRF <br>
    [libraries](https://github.com/lyusupov/SoftRF/tree/master/software/firmware/source/libraries) &nbsp;&nbsp;&nbsp;&nbsp;**-->** ``<Home>``/Energia/libraries <br>

4. change directory on ``<Home>``/Energia/UATbridge
5. create all necessary symbolic links by doing **make links**:

```
$ make links
Creating symlink Platform_CC13XX.cpp  -->  ../SoftRF/Platform_CC13XX.cpp
Creating symlink SoCHelper.cpp  -->  ../SoftRF/SoCHelper.cpp
Creating symlink RFHelper.cpp  -->  ../SoftRF/RFHelper.cpp
Creating symlink GNSSHelper.cpp  -->  ../SoftRF/GNSSHelper.cpp

< ... skipped ... >
```

6. start **Energia** application
7. open **UATbridge** sketch from _File_ -> _Open_ menu
8. [install support](http://energia.nu/guide/boards/) for TI CC13XX familiy with _Tools_ -> _Board_ ->  _Boards_ _Manager..._
9. Select _Tools_ -> _Board_ ->  _LaunchPad_ _w/_ _CC1310_ _EMT_ _(48MHz)_
10. Select _Tools_ -> _Port_ ->  ``<your XDS110 port device name>``
11. Select _Tools_ -> _Programmer_ ->  _dslite_
12. try to build and upload using _Sketch_ -> _Upload_

12a. or, to build the firmware using shell prompt, do:

```
$ make build
energia --verify --verbose-build UATbridge.ino
Picked up JAVA_TOOL_OPTIONS:
Loading configuration...
Initializing packages...
Preparing boards...
Verifying...

< ... skipped ... >
```

13a. inspect **/tmp** directory and sub-folders, take **UATbridge.ino.elf** file and use it with TI's **Uniflash** or **Flash Programmer 2**.<br>

14a. (Optional) if you want to use [**cc2538-bsl.py**](https://github.com/JelmerT/cc2538-bsl) tool to put the firmware into flash memory of CC1310 IC via **boot loader**, run **make ihex**:

```
$ make ihex

< ... skipped ... >
```

<br>

## Validation

Reception capability of the **UAT Receiver** mode was validated both with:

1. **SoftRF WebUI** on ESP32:

<br>



<br>

2. and genuine [**Stratux**](http://stratux.me/) software on a Raspberry Pi:

<br>



Reception capability of real life UAT traffic in **Normal** mode had been validated on **Sun-n-Fun** (2019) Fly-In & Expo in Lakeland, FL:



<p>&nbsp;</p>

## Known limitations

1. reception of UAT signals is currently limited to "downlink" (air-to-air) packets only. So, realtime weather and other "bells and whistles" of the UAT protocol are not available ;
2. due to limited maximum speed of ESP8266's UART, this platform is not able to use **UAT receiver** right now. ESP32 and Raspberry Pi are Ok ;
3. RF settings of CC1310 IC are not optimal yet. This causes average 10-20% packets loss ratio at this time ;
4. "Stock" EByte E70 module has built-in passive HF filter to meet FCC compliance. Because of that, sensitivity @ 978 MHz is reduced by 10-15 dB. To achieve full performance, you need to open the shield and solder a bypass.

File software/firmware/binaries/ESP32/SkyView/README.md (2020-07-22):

## Release notes

### revision 0.10

#### New features

- Bluetooth SPP and LE connection methods. Mostly applicable for a 'SoftRF on ESP32' partner - other devices may or may not work ;
- serial data input over EZ built-in micro-USB port ;
- one more radar view's zoom level ;
- 'Wi-Fi off' timer option ;
- traffic filter (by altitude) ;
- team member's aircraft (if any) is depicted in a bit different manner ;
- dual boot option ( demo application is [iArradio](https://github.com/TioRuben/iArradio) ).

#### Known issues and limitations

- same as in 0.9, plus
- first Bluetooth SPP connection may cause restart of a partner SoftRF data source device ;
- due to high RAM memory usage, Bluetooth SPP may coexist with either voice or aircraft's data option but not both ;
- only Bluetooth 'Simple Pairing' (no key) method is currently supported.

#### Flashing instructions

&nbsp;&nbsp;&nbsp;&nbsp;**Regular:**<br>
&nbsp;&nbsp;&nbsp;&nbsp;&nbsp;&nbsp;&nbsp;&nbsp;&nbsp;&nbsp;&nbsp;&nbsp;'Web Update' UI feature does not work in previous 0.9 revision. Use generic ('cable') method instead.<br>
&nbsp;&nbsp;&nbsp;&nbsp;&nbsp;&nbsp;&nbsp;&nbsp;&nbsp;&nbsp;&nbsp;&nbsp;Follow **Step 1** and **Step 2** of this [**Quick start**](https://github.com/lyusupov/SoftRF/wiki/SkyView.-Quick-start) guidance.

&nbsp;&nbsp;&nbsp;&nbsp;**Dual boot:**<br>
&nbsp;&nbsp;&nbsp;&nbsp;&nbsp;&nbsp;&nbsp;&nbsp;&nbsp;&nbsp;&nbsp;&nbsp;Follow [these instructions](https://github.com/lyusupov/SoftRF/wiki/SkyView.-Dual-boot).<br>
&nbsp;&nbsp;&nbsp;&nbsp;&nbsp;&nbsp;&nbsp;&nbsp;&nbsp;&nbsp;&nbsp;&nbsp;**NOTICE!**: [**iArradio**](https://github.com/TioRuben/iArradio) firmware that comes with it is a DEMO. I will reject your every claim or question.<br>
&nbsp;&nbsp;&nbsp;&nbsp;&nbsp;&nbsp;&nbsp;&nbsp;&nbsp;&nbsp;&nbsp;&nbsp;&nbsp;&nbsp;&nbsp;&nbsp;&nbsp;&nbsp;&nbsp;&nbsp;If you need a custom weather, playlist or timezone - build your own firmware file by yourself.<br>

### revision 0.9

#### Known issues and limitations

- maximum number of tracked objects is limited to 9 ;
- very short keypress may not work. Make a more distinct one ;
- keypress may not work when audio is playing ;
- view mode change may cause 2-3 seconds of '**NO DATA**' or '**NO FIX**' warning ;
- 'anti-ghosting' full screen refresh may cause 2-3 seconds of '**NO DATA**' or '**NO FIX**' warning ;
- '**NO DATA**' or '**NO FIX**' warning may appear right after voice traffic alert message ;
- **VOICE2** and **VOICE3** may have some WAV files missing ;
- Wi-Fi re-connect may fail sometimes. Reset of SoftRF server and/or SkyView client does typically help ;
- does not work with Stratux yet due to issues with DHCP leases and GDL90 data (over-)flow.

### revision 0.8

Very first deployment of SkyView's firmware binaries.

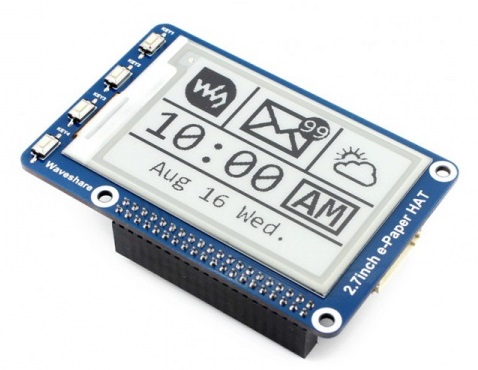
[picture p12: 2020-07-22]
documents/images/bom/epaper-hat.jpg

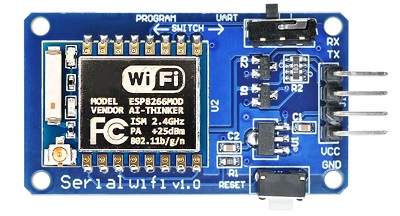
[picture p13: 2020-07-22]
documents/images/WebTop-4.jpg

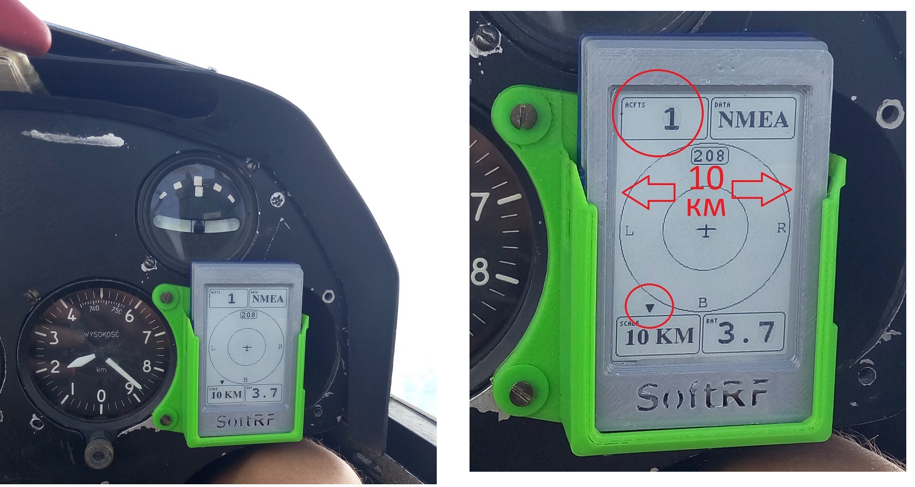
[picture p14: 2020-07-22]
documents/images/skyview-30-distance.jpg

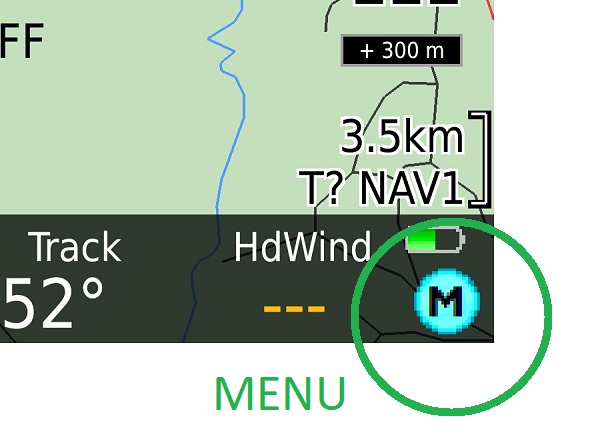
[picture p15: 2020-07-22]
documents/images/t-motion-36.jpg

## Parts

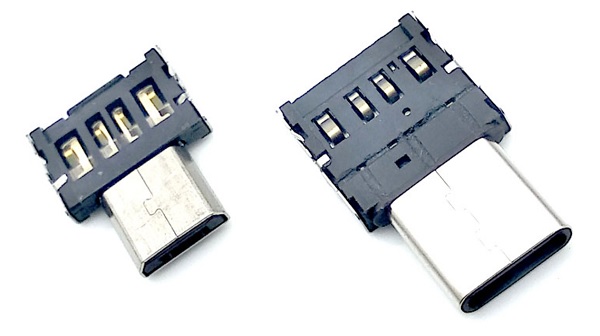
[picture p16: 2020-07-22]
documents/images/bom/musb-typec.jpg

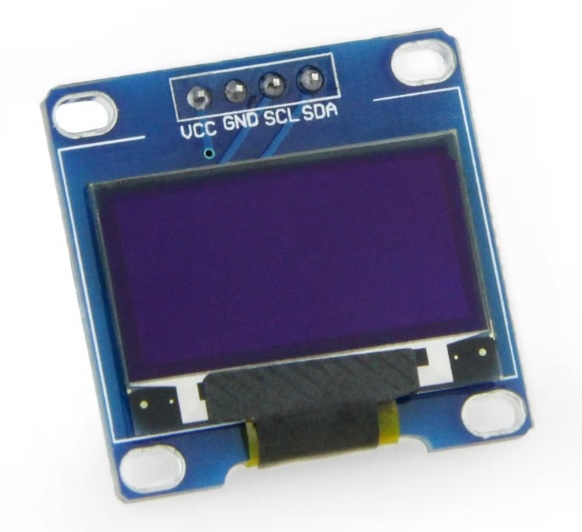
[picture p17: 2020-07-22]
documents/images/bom/oled-096.jpg

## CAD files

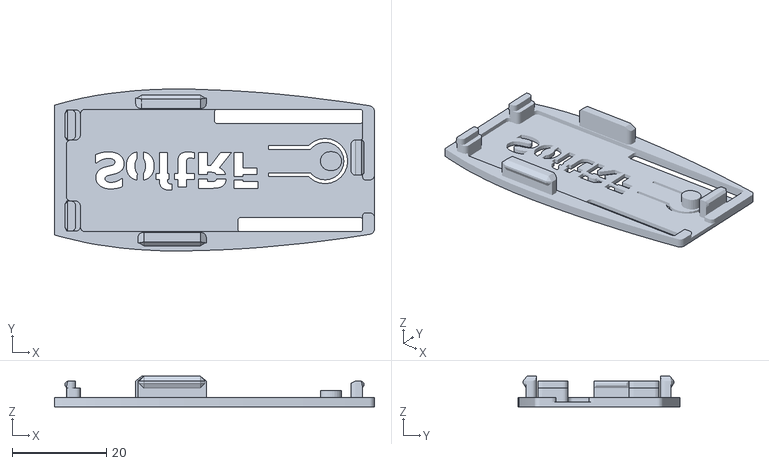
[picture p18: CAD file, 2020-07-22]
case/Dongle/SoftRF-Case-Dongle-Slim-Lid.stl
68.0 x 34.4 x 6.50

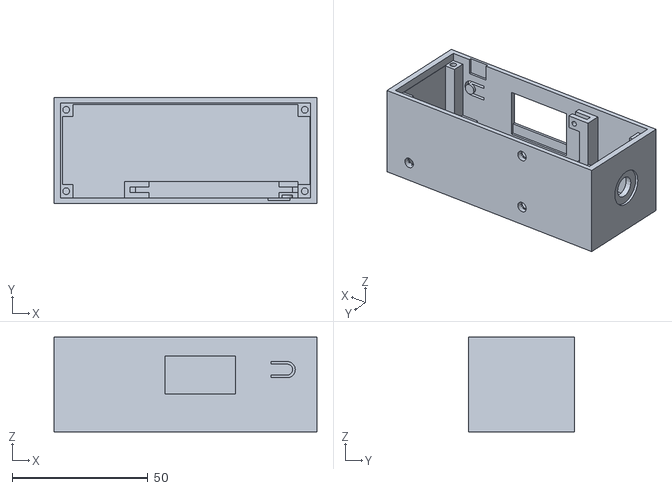
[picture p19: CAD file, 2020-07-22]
case/lora32/SoftRF-Lora32-case.stl
97.0 x 39.0 x 35.0

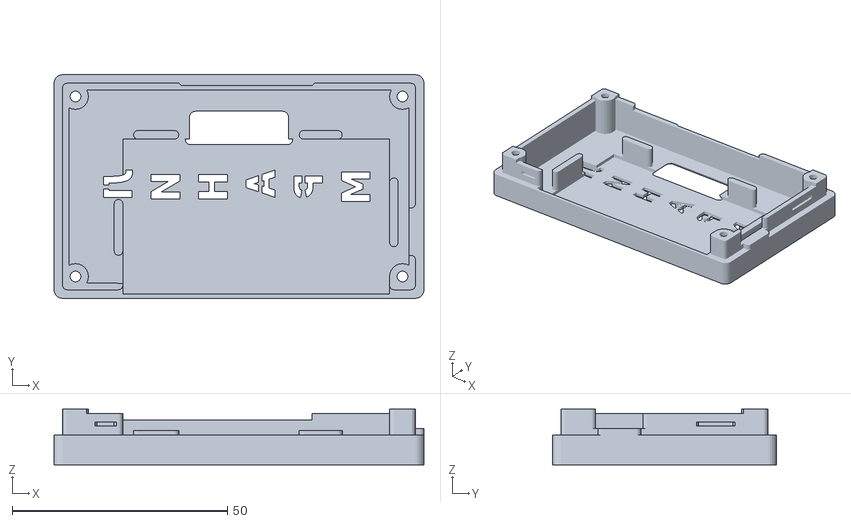
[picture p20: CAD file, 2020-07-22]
case/SkyView/SkyView-Case-EZ-Body-plus.stl
86.0 x 52.0 x 13.0

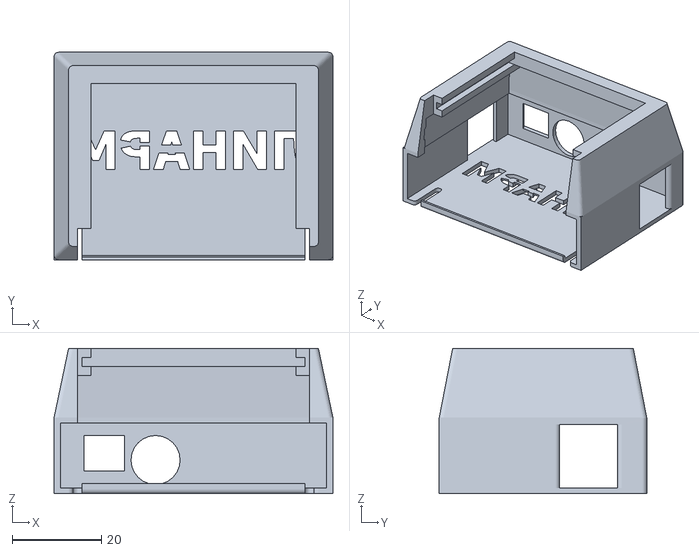
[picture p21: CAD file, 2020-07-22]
case/Uni/SoftRF-Case-Uni-Sleeve.stl
62.5 x 46.5 x 32.5

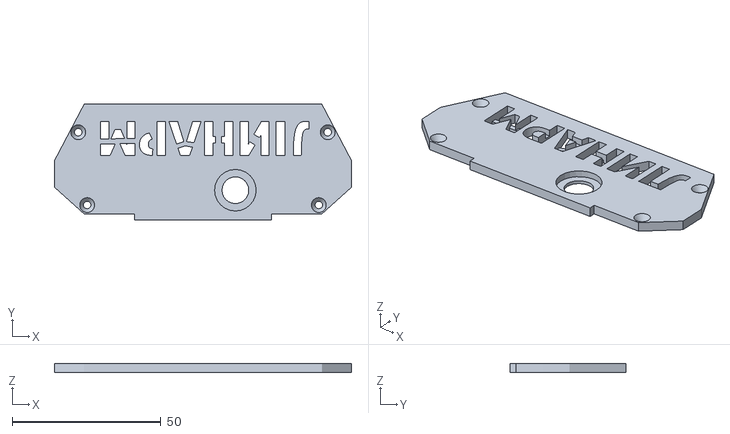
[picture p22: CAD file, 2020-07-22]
case/v5/SoftRF-Case-Prime2-Lid-V08.stl
100.0 x 39.0 x 3.00

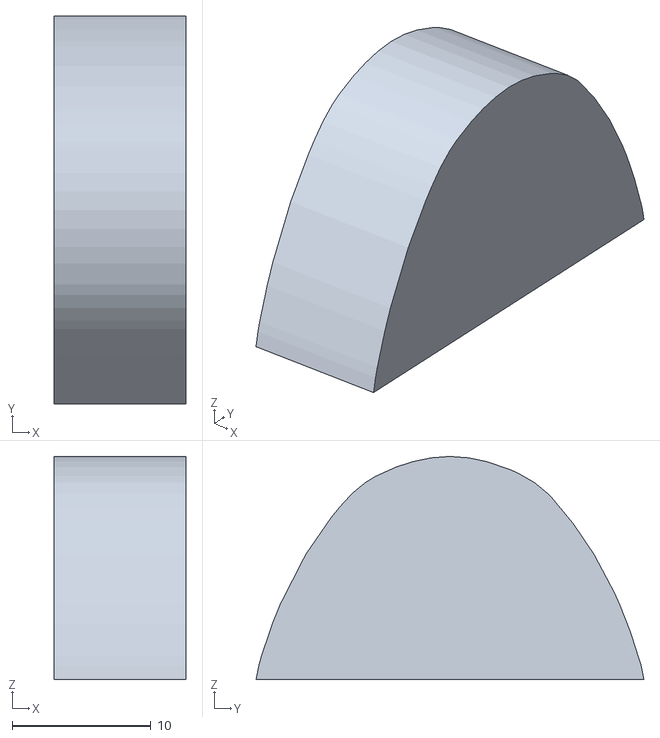
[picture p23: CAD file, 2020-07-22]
case/Dongle/SoftRF-Case-Dongle-Slim-Cap.stl
9.50 x 28.0 x 16.1

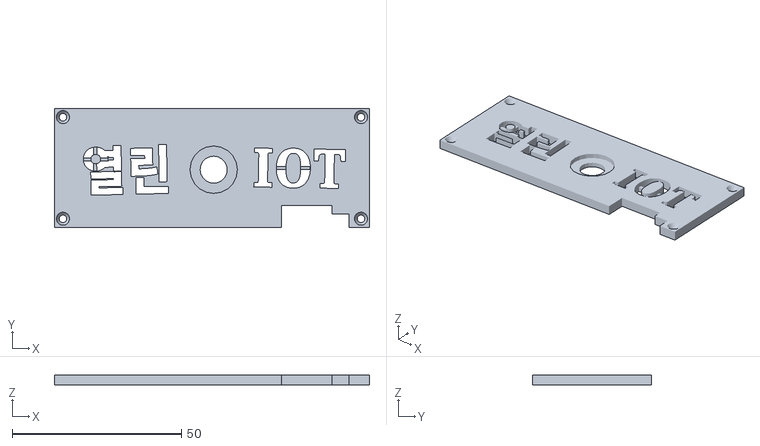
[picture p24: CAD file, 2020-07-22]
case/lora32/SoftRF-Lora32-case-top.stl
93.0 x 35.0 x 3.00

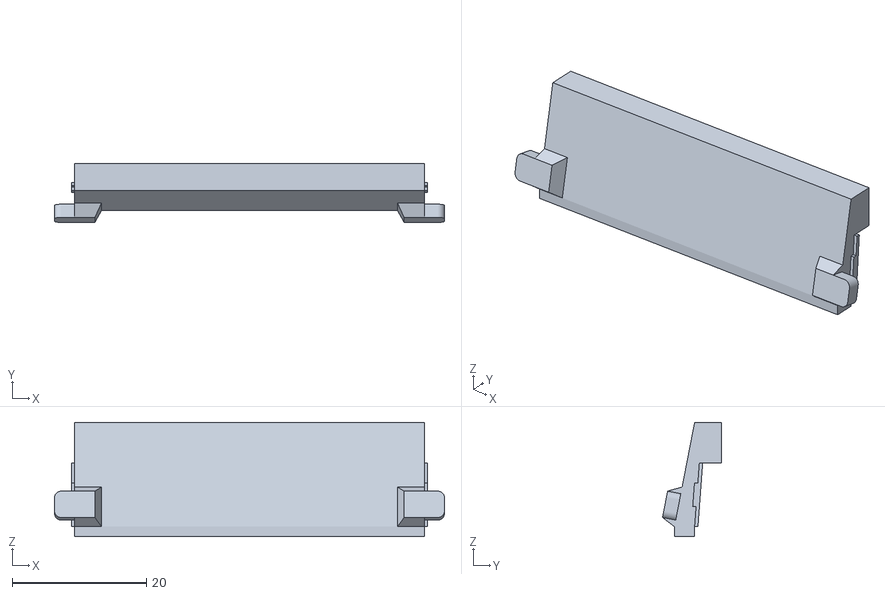
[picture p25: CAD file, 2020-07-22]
case/Uni/SoftRF-Case-Uni-Wall.stl
58.0 x 8.77 x 17.0

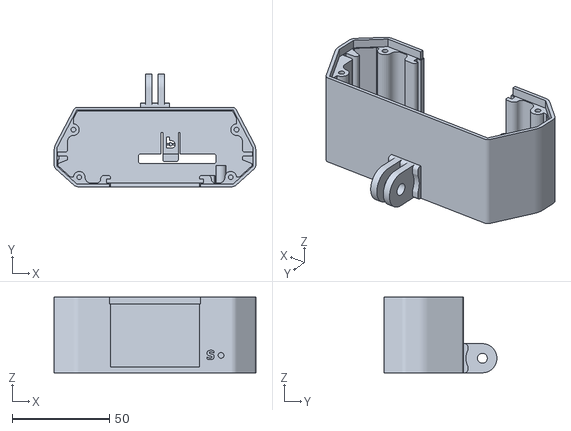
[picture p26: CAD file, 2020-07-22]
case/v5/SoftRF-Case-Prime2-Body-V11-GoPro.stl
104.0 x 58.1 x 39.0

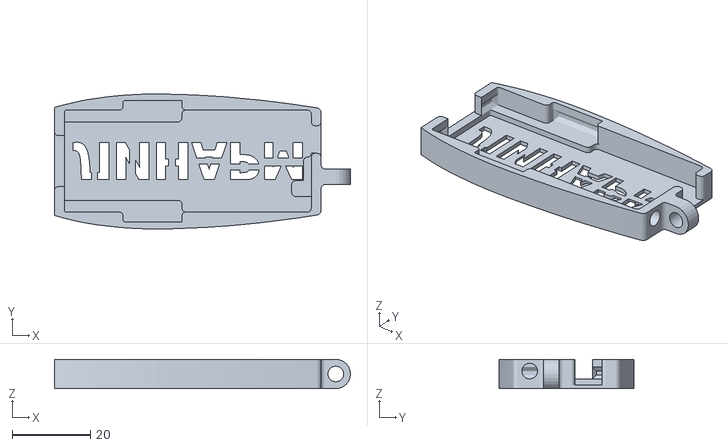
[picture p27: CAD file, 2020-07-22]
case/Dongle/SoftRF-Case-Dongle-Slim-Body.stl
75.5 x 34.4 x 7.50

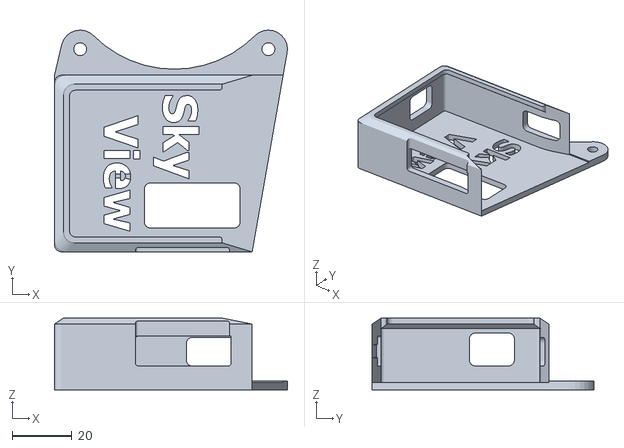
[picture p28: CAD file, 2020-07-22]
case/SkyView/SkyView-Case-EZ-Holder.stl
77.8 x 74.1 x 24.0

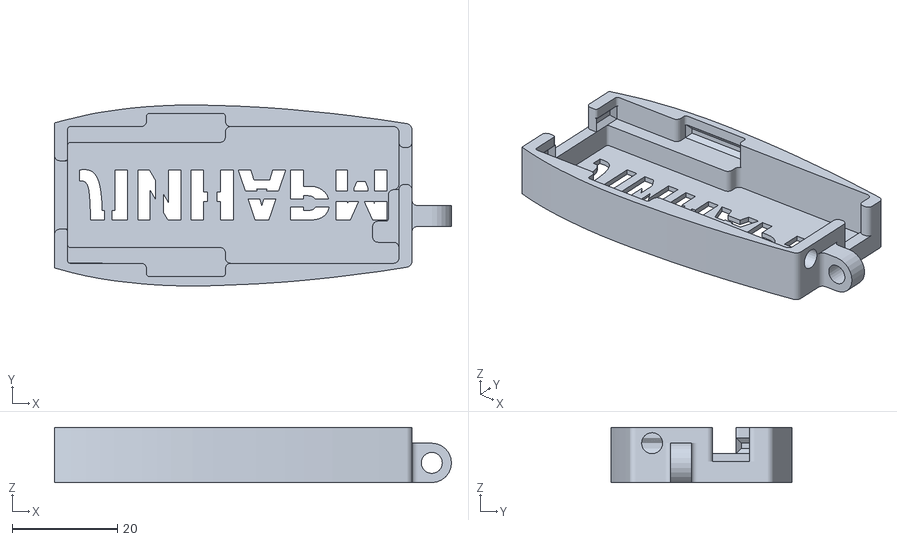
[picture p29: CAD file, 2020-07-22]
case/Dongle/SoftRF-Case-Dongle-Battery-Body.stl
75.5 x 34.4 x 10.5

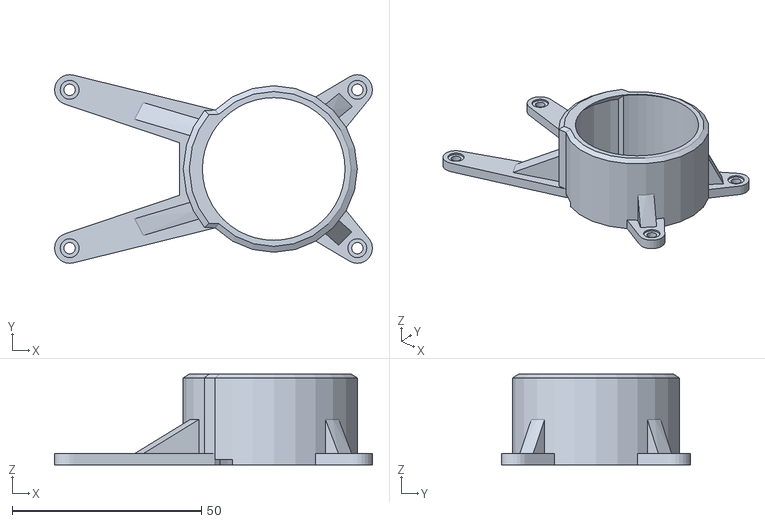
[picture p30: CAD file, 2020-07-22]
case/SkyView/SkyView-Case-EZ-Speaker-40mm.stl
84.0 x 49.8 x 24.0

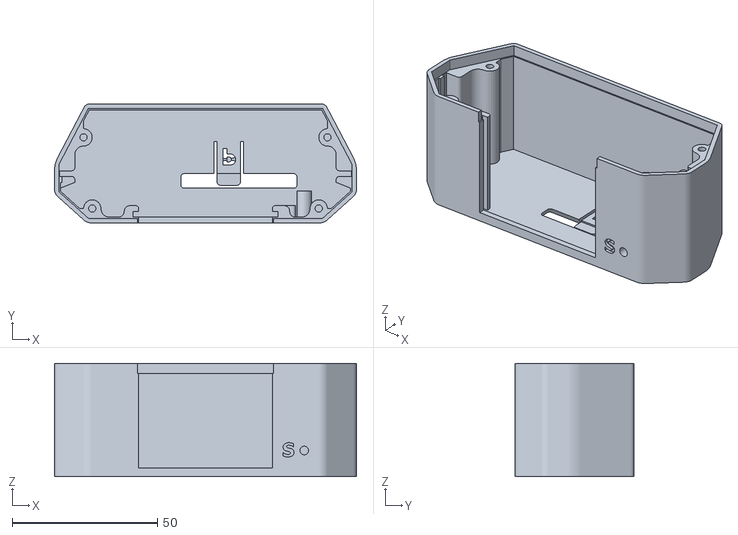
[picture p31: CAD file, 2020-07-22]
case/v5/SoftRF-Case-Prime2-Body-V11.stl
104.0 x 41.0 x 39.0

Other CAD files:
case/SkyView/SkyView-Case-EZ-Body.stl
case/Dongle/SoftRF-Case-Dongle-OLED-Lid.stl
case/v5/SoftRF-Case-Prime2-OLED-Front-TTGO.stl
case/Dongle/SoftRF-Case-Dongle-Cap-16mm.stl
case/Dongle/SoftRF-Case-Dongle-Slim-Lid-NoPinHead.stl
case/v5/SoftRF-Case-Prime2-Body-V08-GoPro.stl
case/v5/SoftRF-Case-Prime2-Body-V08.stl
case/v5/SoftRF-Case-Prime2-Lid-V08-bumper.stl

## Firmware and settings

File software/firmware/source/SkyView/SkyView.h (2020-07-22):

/*
 * SkyView.h
 * Copyright (C) 2019-2020 Linar Yusupov
 *
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
 * You should have received a copy of the GNU General Public License
 * along with this program.  If not, see <http://www.gnu.org/licenses/>.
 */

#ifndef SKYVIEW_H
#define SKYVIEW_H

#define SKYVIEW_FIRMWARE_VERSION  "0.10"
#define SKYVIEW_IDENT     "SkyView-"

#define DEFAULT_AP_SSID   "SoftRF-abc123"
#define DEFAULT_AP_PSK    "12345678"

#define RELAY_DST_PORT    12390
#define RELAY_SRC_PORT    (RELAY_DST_PORT - 1)

/* SoftRF serial output defaults */
#define SERIAL_OUT_BR     38400
#define SERIAL_OUT_BITS   SERIAL_8N1

#define DATA_TIMEOUT      2000 /* 2.0 seconds */

#define MAX_FILENAME_LEN  64
#define WAV_FILE_SUFFIX   ".wav"
#define VOICE1_SUBDIR     "voice1/"
#define VOICE2_SUBDIR     "voice2/"
#define VOICE3_SUBDIR     "voice3/"

typedef struct hardware_info {
    byte  model;
    byte  revision;
    byte  soc;
    byte  display;

} hardware_info_t;

enum
{
	SOFTRF_MODEL_STANDALONE,
	SOFTRF_MODEL_PRIME,
	SOFTRF_MODEL_UAV,
	SOFTRF_MODEL_PRIME_MK2,
	SOFTRF_MODEL_RASPBERRY,
	SOFTRF_MODEL_UAT,
	SOFTRF_MODEL_SKYVIEW,
	SOFTRF_MODEL_RETRO,
	SOFTRF_MODEL_SKYWATCH
};

enum
{
	HW_REV_UNKNOWN,
	HW_REV_DEVKIT,
	HW_REV_T5S_1_9,
	HW_REV_T5S_2_8,
	HW_REV_T8_1_8
};

enum
{
	DISPLAY_NONE,
	DISPLAY_EPD_2_7,
	DISPLAY_OLED_2_4
};

enum
{
	ADAPTER_WAVESHARE_PI_HAT_2_7,
	ADAPTER_WAVESHARE_ESP8266,
	ADAPTER_WAVESHARE_ESP32,
	ADAPTER_TTGO_T5S,
	ADAPTER_NODEMCU,
	ADAPTER_OLED
};

enum
{
	CON_NONE,
	CON_SERIAL,
	CON_WIFI_UDP,
	CON_WIFI_TCP,
	CON_BLUETOOTH_SPP,
	CON_BLUETOOTH_LE
};

enum
{
	B4800,
	B9600,
	B19200,
	B38400,
	B57600,
	B115200,
	B2000000
};

enum
{
	PROTOCOL_NONE,
	PROTOCOL_NMEA, /* FTD-12 */
	PROTOCOL_GDL90,
	PROTOCOL_MAVLINK_1,
	PROTOCOL_MAVLINK_2,
	PROTOCOL_D1090,
	PROTOCOL_UATRADIO
};

enum
{
	UNITS_METRIC,
	UNITS_IMPERIAL,
	UNITS_MIXED     // almost the same as metric, but all the altitudes are in feet
};

enum
{
	VIEW_MODE_RADAR,
	VIEW_MODE_TABLE,
	VIEW_MODE_TEXT
};

enum
{
	DIRECTION_TRACK_UP,
	DIRECTION_NORTH_UP
};

/*
 * 'Radar view' scale factor (outer circle diameter)
 *
 * Metric and Mixed:
 *  LOWEST - 20 KM diameter (10 KM radius)
 *  LOW    - 10 KM diameter ( 5 KM radius)
 *  MEDIUM -  4 KM diameter ( 2 KM radius)
 *  HIGH   -  2 KM diameter ( 1 KM radius)
 *
 * Imperial:
 *  LOWEST - 10 NM diameter (  5 NM radius)
 *  LOW    -  5 NM diameter (2.5 NM radius)
 *  MEDIUM -  2 NM diameter (  1 NM radius)
 *  HIGH   -  1 NM diameter (0.5 NM radius)
 */
enum
{
	ZOOM_LOWEST,
	ZOOM_LOW,
	ZOOM_MEDIUM,
	ZOOM_HIGH
};

enum
{
	ID_REG,
	ID_TAIL,
	ID_MAM
};

enum
{
	VOICE_OFF,
	VOICE_1,
	VOICE_2,
	VOICE_3
};

enum
{
	ANTI_GHOSTING_OFF,
	ANTI_GHOSTING_AUTO,
	ANTI_GHOSTING_2MIN,
	ANTI_GHOSTING_5MIN,
	ANTI_GHOSTING_10MIN
};

enum
{
	POWER_SAVE_NONE = 0,
	POWER_SAVE_WIFI = 1,
	POWER_SAVE_GNSS = 2
};

enum
{
	TRAFFIC_FILTER_OFF,
	TRAFFIC_FILTER_500M,
	TRAFFIC_FILTER_1500M
};

enum
{
	DB_NONE,
	DB_AUTO,
	DB_FLN,
	DB_OGN,
	DB_ICAO
};

extern hardware_info_t hw_info;

extern void shutdown(const char *);
extern void Input_loop(void);

#endif /* SKYVIEW_H */

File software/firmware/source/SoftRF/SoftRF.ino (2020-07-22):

/*
 * SoftRF(.ino) firmware
 * Copyright (C) 2016-2020 Linar Yusupov
 *
 * Author: Linar Yusupov, linar.r.yusupov@gmail.com
 *
 * Web: http://github.com/lyusupov/SoftRF
 *
 * Credits:
 *   Arduino core for ESP8266 is developed/supported by ESP8266 Community (support-esp8266@esp8266.com)
 *   AVR/Arduino nRF905 Library/Driver is developed by Zak Kemble, contact@zakkemble.co.uk
 *   flarm_decode is developed by Stanislaw Pusep, http://github.com/creaktive
 *   Arduino Time Library is developed by Paul Stoffregen, http://github.com/PaulStoffregen
 *   "Aircraft" and MAVLink Libraries are developed by Andy Little
 *   TinyGPS++ and PString Libraries are developed by Mikal Hart
 *   Adafruit NeoPixel Library is developed by Phil Burgess, Michael Miller and others
 *   TrueRandom Library is developed by Peter Knight
 *   IBM LMIC and Semtech Basic MAC frameworks for Arduino are maintained by Matthijs Kooijman
 *   ESP8266FtpServer is developed by David Paiva
 *   Lib_crc is developed by Lammert Bies
 *   OGN library is developed by Pawel Jalocha
 *   NMEA library is developed by Timur Sinitsyn, Tobias Simon, Ferry Huberts
 *   ADS-B encoder C++ library is developed by yangbinbin (yangbinbin_ytu@163.com)
 *   Arduino Core for ESP32 is developed by Hristo Gochkov
 *   ESP32 BT SPP library is developed by Evandro Copercini
 *   Adafruit BMP085 library is developed by Limor Fried and Ladyada
 *   Adafruit BMP280 library is developed by Kevin Townsend
 *   Adafruit MPL3115A2 library is developed by Limor Fried and Kevin Townsend
 *   U8g2 monochrome LCD, OLED and eInk library is developed by Oliver Kraus
 *   NeoPixelBus library is developed by Michael Miller
 *   jQuery library is developed by JS Foundation
 *   EGM96 data is developed by XCSoar team
 *   BCM2835 C library is developed by Mike McCauley
 *   SimpleNetwork library is developed by Dario Longobardi
 *   ArduinoJson library is developed by Benoit Blanchon
 *   Flashrom library is part of the flashrom.org project
 *   Arduino Core for TI CC13X0 and CC13X2 is developed by Robert Wessels
 *   EasyLink library is developed by Robert Wessels and Tony Cave
 *   Dump978 library is developed by Oliver Jowett
 *   FEC library is developed by Phil Karn
 *   AXP202X library is developed by Lewis He
 *   Arduino Core for STM32 is developed by Frederic Pillon
 *   TFT library is developed by Bodmer
 *   STM32duino Low Power and RTC libraries are developed by Wi6Labs
 *   Basic MAC library is developed by Michael Kuyper
 *   LowPowerLab SPIFlash library is maintained by Felix Rusu
 *   Arduino core for ASR650x is developed by Aaron Lee (HelTec Automation)
 *
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
 * You should have received a copy of the GNU General Public License
 * along with this program.  If not, see <http://www.gnu.org/licenses/>.
 */

#include "OTAHelper.h"
#include "TimeHelper.h"
#include "LEDHelper.h"
#include "GNSSHelper.h"
#include "RFHelper.h"
#include "SoundHelper.h"
#include "EEPROMHelper.h"
#include "BatteryHelper.h"
#include "MAVLinkHelper.h"
#include "GDL90Helper.h"
#include "NMEAHelper.h"
#include "D1090Helper.h"
#include "SoCHelper.h"
#include "WiFiHelper.h"
#include "WebHelper.h"
#include "BaroHelper.h"
#include "TTNHelper.h"
#include "TrafficHelper.h"

#if defined(ENABLE_AHRS)
#include "AHRSHelper.h"
#endif /* ENABLE_AHRS */

#if LOGGER_IS_ENABLED
#include "LogHelper.h"
#endif /* LOGGER_IS_ENABLED */

#define DEBUG 0
#define DEBUG_TIMING 0

#define isTimeToDisplay() (millis() - LEDTimeMarker > 1000)
#define isTimeToExport() (millis() - ExportTimeMarker > 1000)

ufo_t ThisAircraft;

hardware_info_t hw_info = {
  .model    = DEFAULT_SOFTRF_MODEL,
  .revision = 0,
  .soc      = SOC_NONE,
  .rf       = RF_IC_NONE,
  .gnss     = GNSS_MODULE_NONE,
  .baro     = BARO_MODULE_NONE,
  .display  = DISPLAY_NONE
};

unsigned long LEDTimeMarker = 0;
unsigned long ExportTimeMarker = 0;

void setup()
{
  rst_info *resetInfo;

  hw_info.soc = SoC_setup(); // Has to be very first procedure in the execution order

  resetInfo = (rst_info *) SoC->getResetInfoPtr();

  Serial.begin(SERIAL_OUT_BR, SERIAL_OUT_BITS);

#if defined(USBD_USE_CDC) && !defined(DISABLE_GENERIC_SERIALUSB)
  /* Let host's USB and console drivers to warm-up */
  delay(2000);
#endif

#if LOGGER_IS_ENABLED && !defined(SDGPXLOG)
  Logger_setup();
#endif /* LOGGER_IS_ENABLED */

  Serial.println();
  Serial.print(F(SOFTRF_IDENT));
  Serial.print(SoC->name);
  Serial.print(F(" FW.REV: " SOFTRF_FIRMWARE_VERSION " DEV.ID: "));
  Serial.println(String(SoC->getChipId(), HEX));
  Serial.println(F("Copyright (C) 2015-2020 Linar Yusupov. All rights reserved."));
  Serial.flush();

  if (resetInfo) {
    Serial.println(""); Serial.print(F("Reset reason: ")); Serial.println(resetInfo->reason);
  }
  Serial.println(SoC->getResetReason());
  Serial.print(F("Free heap size: ")); Serial.println(SoC->getFreeHeap());
  Serial.println(SoC->getResetInfo()); Serial.println("");

  EEPROM_setup();

  SoC->Button_setup();

  ThisAircraft.addr = SoC->getChipId() & 0x00FFFFFF;

  hw_info.rf = RF_setup();

  if (hw_info.model    == SOFTRF_MODEL_PRIME_MK2 &&
      hw_info.revision == 2                      &&
      RF_SX12XX_RST_is_connected)
  {
    hw_info.revision = 5;
  }

  delay(100);

  hw_info.baro = Baro_setup();
#if defined(ENABLE_AHRS)
  hw_info.ahrs = AHRS_setup();
#endif /* ENABLE_AHRS */
  hw_info.display = SoC->Display_setup();

#if !defined(EXCLUDE_MAVLINK)
  if (settings->mode == SOFTRF_MODE_UAV) {
    Serial.begin(57600);
    MAVLink_setup();
    ThisAircraft.aircraft_type = AIRCRAFT_TYPE_UAV;  
  }  else
#endif /* EXCLUDE_MAVLINK */
  {
    hw_info.gnss = GNSS_setup();
    ThisAircraft.aircraft_type = settings->aircraft_type;
  }
  ThisAircraft.protocol = settings->rf_protocol;
  ThisAircraft.stealth  = settings->stealth;
  ThisAircraft.no_track = settings->no_track;

  Battery_setup();
  Traffic_setup();

  SoC->swSer_enableRx(false);

  LED_setup();

  WiFi_setup();

  if (SoC->Bluetooth) {
     SoC->Bluetooth->setup();
  }
#if LOGGER_IS_ENABLED && defined(SDGPXLOG)
  Logger_setup();
#endif /* LOGGER_IS_ENABLED */

  OTA_setup();
  Web_setup();
  NMEA_setup();

#if defined(ENABLE_TTN)
  TTN_setup();
#endif

  delay(1000);

  /* expedite restart on WDT reset */
  if (resetInfo->reason != REASON_WDT_RST) {
    LED_test();
  }

  SoC->Sound_test(resetInfo->reason);

  switch (settings->mode)
  {
  case SOFTRF_MODE_TXRX_TEST:
  case SOFTRF_MODE_WATCHOUT:
    Time_setup();
    break;
  case SOFTRF_MODE_BRIDGE:
    break;
  case SOFTRF_MODE_NORMAL:
  case SOFTRF_MODE_UAV:
  default:
    SoC->swSer_enableRx(true);
    break;
  }

  SoC->WDT_setup();
}

void loop()
{
  // Do common RF stuff first
  RF_loop();

  switch (settings->mode)
  {
#if !defined(EXCLUDE_TEST_MODE)
  case SOFTRF_MODE_TXRX_TEST:
    txrx_test();
    break;
#endif /* EXCLUDE_TEST_MODE */
#if !defined(EXCLUDE_MAVLINK)
  case SOFTRF_MODE_UAV:
    uav();
    break;
#endif /* EXCLUDE_MAVLINK */
#if !defined(EXCLUDE_WIFI)
  case SOFTRF_MODE_BRIDGE:
    bridge();
    break;
#endif /* EXCLUDE_WIFI */
  case SOFTRF_MODE_WATCHOUT:
    watchout();
    break;
  case SOFTRF_MODE_NORMAL:
  default:
    normal();
    break;
  }

  // Show status info on tiny OLED display
  SoC->Display_loop();

  // battery status LED
  LED_loop();

  // Handle DNS
  WiFi_loop();

  // Handle Web
  Web_loop();

  // Handle OTA update.
  OTA_loop();

#if LOGGER_IS_ENABLED
  Logger_loop();
#endif /* LOGGER_IS_ENABLED */

  SoC->loop();

  Battery_loop();

  SoC->Button_loop();

  yield();
}

void shutdown(const char *msg)
{
  SoC->WDT_fini();

  SoC->swSer_enableRx(false);

  NMEA_fini();

  Web_fini();

  WiFi_fini();

  if (settings->mode != SOFTRF_MODE_UAV) {
    GNSS_fini();
  }

  SoC->Display_fini(msg);

  RF_Shutdown();

  SoC->Button_fini();

  SoC_fini();
}

void normal()
{
  bool success;

  Baro_loop();

#if defined(ENABLE_AHRS)
  AHRS_loop();
#endif /* ENABLE_AHRS */

  GNSS_loop();

  ThisAircraft.timestamp = now();
  if (isValidFix()) {
    ThisAircraft.latitude = gnss.location.lat();
    ThisAircraft.longitude = gnss.location.lng();
    ThisAircraft.altitude = gnss.altitude.meters();
    ThisAircraft.course = gnss.course.deg();
    ThisAircraft.speed = gnss.speed.knots();
    ThisAircraft.hdop = (uint16_t) gnss.hdop.value();
    ThisAircraft.geoid_separation = gnss.separation.meters();

#if !defined(EXCLUDE_EGM96)
    /*
     * When geoidal separation is zero or not available - use approx. EGM96 value
     */
    if (ThisAircraft.geoid_separation == 0.0) {
      ThisAircraft.geoid_separation = (float) LookupSeparation(
                                                ThisAircraft.latitude,
                                                ThisAircraft.longitude
                                              );
      /* we can assume the GPS unit is giving ellipsoid height */
      ThisAircraft.altitude -= ThisAircraft.geoid_separation;
    }
#endif /* EXCLUDE_EGM96 */

    RF_Transmit(RF_Encode(&ThisAircraft), true);
  }

  success = RF_Receive();

#if DEBUG
  success = true;
#endif

  if (success && isValidFix()) ParseData();

#if defined(ENABLE_TTN)
  TTN_loop();
#endif

  if (isValidFix()) {
    Traffic_loop();
  }

  if (isTimeToDisplay()) {
    if (isValidFix()) {
      LED_DisplayTraffic();
    } else {
      LED_Clear();
    }
    LEDTimeMarker = millis();
  }

  if (isTimeToExport()) {
    NMEA_Export();

    if (isValidFix()) {
      GDL90_Export();
      D1090_Export();
    }
    ExportTimeMarker = millis();
  }

  // Handle Air Connect
  NMEA_loop();

  ClearExpired();

}

#if !defined(EXCLUDE_MAVLINK)
void uav()
{
  bool success = false;

  PickMAVLinkFix();

  MAVLinkTimeSync();
  MAVLinkSetWiFiPower();

  ThisAircraft.timestamp = now();

  if (isValidMAVFix()) {
    ThisAircraft.latitude = the_aircraft.location.gps_lat / 1e7;
    ThisAircraft.longitude = the_aircraft.location.gps_lon / 1e7;
    ThisAircraft.altitude = the_aircraft.location.gps_alt / 1000.0;
    ThisAircraft.course = the_aircraft.location.gps_cog;
    ThisAircraft.speed = (the_aircraft.location.gps_vog / 100.0) / _GPS_MPS_PER_KNOT;
    ThisAircraft.pressure_altitude = the_aircraft.location.baro_alt;
    ThisAircraft.hdop = the_aircraft.location.gps_hdop;

    RF_Transmit(RF_Encode(&ThisAircraft), true);
  }

  success = RF_Receive();

  if (success && isValidMAVFix()) ParseData();

  if (isTimeToExport() && isValidMAVFix()) {
    MAVLinkShareTraffic();
    ExportTimeMarker = millis();
  }

  ClearExpired();
}
#endif /* EXCLUDE_MAVLINK */

#if !defined(EXCLUDE_WIFI)
void bridge()
{
  bool success;

  size_t tx_size = Raw_Receive_UDP(&TxBuffer[0]);

  if (tx_size > 0) {
    RF_Transmit(tx_size, true);
  }

  success = RF_Receive();

  if(success)
  {
    size_t rx_size = RF_Payload_Size(settings->rf_protocol);
    rx_size = rx_size > sizeof(fo.raw) ? sizeof(fo.raw) : rx_size;

    memset(fo.raw, 0, sizeof(fo.raw));
    memcpy(fo.raw, RxBuffer, rx_size);

    if (settings->nmea_p) {
      StdOut.print(F("$PSRFI,"));
      StdOut.print((unsigned long) now());    StdOut.print(F(","));
      StdOut.print(Bin2Hex(fo.raw, rx_size)); StdOut.print(F(","));
      StdOut.println(RF_last_rssi);
    }

    Raw_Transmit_UDP();
  }

  if (isTimeToDisplay()) {
    LED_Clear();
    LEDTimeMarker = millis();
  }
}
#endif /* EXCLUDE_WIFI */

void watchout()
{
  bool success;

  success = RF_Receive();

  if (success) {
    size_t rx_size = RF_Payload_Size(settings->rf_protocol);
    rx_size = rx_size > sizeof(fo.raw) ? sizeof(fo.raw) : rx_size;

    memset(fo.raw, 0, sizeof(fo.raw));
    memcpy(fo.raw, RxBuffer, rx_size);

    if (settings->nmea_p) {
      StdOut.print(F("$PSRFI,"));
      StdOut.print((unsigned long) now());    StdOut.print(F(","));
      StdOut.print(Bin2Hex(fo.raw, rx_size)); StdOut.print(F(","));
      StdOut.println(RF_last_rssi);
    }
  }

  if (isTimeToDisplay()) {
    LED_Clear();
    LEDTimeMarker = millis();
  }
}

#if !defined(EXCLUDE_TEST_MODE)

unsigned int pos_ndx = 0;
unsigned long TxPosUpdMarker = 0;

void txrx_test()
{
  bool success = false;
#if DEBUG_TIMING
  unsigned long baro_start_ms, baro_end_ms;
  unsigned long tx_start_ms, tx_end_ms, rx_start_ms, rx_end_ms;
  unsigned long parse_start_ms, parse_end_ms, led_start_ms, led_end_ms;
  unsigned long export_start_ms, export_end_ms;
  unsigned long oled_start_ms, oled_end_ms;
#endif
  ThisAircraft.timestamp = now();

  if (TxPosUpdMarker == 0 || (millis() - TxPosUpdMarker) > 4000 ) {
    ThisAircraft.latitude =  pgm_read_float( &txrx_test_positions[pos_ndx][0]);
    ThisAircraft.longitude =  pgm_read_float( &txrx_test_positions[pos_ndx][1]);
    pos_ndx = (pos_ndx + 1) % TXRX_TEST_NUM_POSITIONS;
    TxPosUpdMarker = millis();
  }
  ThisAircraft.altitude = TXRX_TEST_ALTITUDE;
  ThisAircraft.course = TXRX_TEST_COURSE;
  ThisAircraft.speed = TXRX_TEST_SPEED;
  ThisAircraft.vs = TXRX_TEST_VS;

#if DEBUG_TIMING
  baro_start_ms = millis();
#endif
  Baro_loop();
#if DEBUG_TIMING
  baro_end_ms = millis();
#endif

#if defined(ENABLE_AHRS)
  AHRS_loop();
#endif /* ENABLE_AHRS */

#if DEBUG_TIMING
  tx_start_ms = millis();
#endif
  RF_Transmit(RF_Encode(&ThisAircraft), true);
#if DEBUG_TIMING
  tx_end_ms = millis();
  rx_start_ms = millis();
#endif
  success = RF_Receive();
#if DEBUG_TIMING
  rx_end_ms = millis();
#endif

#if DEBUG_TIMING
  parse_start_ms = millis();
#endif
  if (success) ParseData();
#if DEBUG_TIMING
  parse_end_ms = millis();
#endif

#if defined(ENABLE_TTN)
  TTN_loop();
#endif

  Traffic_loop();

#if DEBUG_TIMING
  led_start_ms = millis();
#endif
  if (isTimeToDisplay()) {
    LED_DisplayTraffic();
    LEDTimeMarker = millis();
  }
#if DEBUG_TIMING
  led_end_ms = millis();
#endif

#if DEBUG_TIMING
  export_start_ms = millis();
#endif
  if (isTimeToExport()) {
#if defined(USE_NMEALIB)
    NMEA_Position();
#endif
    NMEA_Export();
    GDL90_Export();
    D1090_Export();
    ExportTimeMarker = millis();
  }
#if DEBUG_TIMING
  export_end_ms = millis();
#endif

#if DEBUG_TIMING
  oled_start_ms = millis();
#endif
//  SoC->Display_loop();
#if DEBUG_TIMING
  oled_end_ms = millis();
#endif

#if DEBUG_TIMING
  if (baro_start_ms - baro_end_ms) {
    Serial.print(F("Baro start: "));
    Serial.print(baro_start_ms);
    Serial.print(F(" Baro stop: "));
    Serial.println(baro_end_ms);
  }
  if (tx_end_ms - tx_start_ms) {
    Serial.print(F("TX start: "));
    Serial.print(tx_start_ms);
    Serial.print(F(" TX stop: "));
    Serial.println(tx_end_ms);
  }
  if (rx_end_ms - rx_start_ms) {
    Serial.print(F("RX start: "));
    Serial.print(rx_start_ms);
    Serial.print(F(" RX stop: "));
    Serial.println(rx_end_ms);
  }
  if (parse_end_ms - parse_start_ms) {
    Serial.print(F("Parse start: "));
    Serial.print(parse_start_ms);
    Serial.print(F(" Parse stop: "));
    Serial.println(parse_end_ms);
  }
  if (led_end_ms - led_start_ms) {
    Serial.print(F("LED start: "));
    Serial.print(led_start_ms);
    Serial.print(F(" LED stop: "));
    Serial.println(led_end_ms);
  }
  if (export_end_ms - export_start_ms) {
    Serial.print(F("Export start: "));
    Serial.print(export_start_ms);
    Serial.print(F(" Export stop: "));
    Serial.println(export_end_ms);
  }
  if (oled_end_ms - oled_start_ms) {
    Serial.print(F("OLED start: "));
    Serial.print(oled_start_ms);
    Serial.print(F(" OLED stop: "));
    Serial.println(oled_end_ms);
  }
#endif

  // Handle Air Connect
  NMEA_loop();

  ClearExpired();
}

#endif /* EXCLUDE_TEST_MODE */

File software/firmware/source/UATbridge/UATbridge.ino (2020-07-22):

/*
 * UATbridge(.ino) firmware
 * Copyright (C) 2019-2020 Linar Yusupov
 *
 * Author: Linar Yusupov, linar.r.yusupov@gmail.com
 *
 * Web: http://github.com/lyusupov/SoftRF
 *
 *
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
 * You should have received a copy of the GNU General Public License
 * along with this program.  If not, see <http://www.gnu.org/licenses/>.
 */

#include "SoCHelper.h"
#include "TimeHelper.h"
#include "LEDHelper.h"
#include "GNSSHelper.h"
#include "RFHelper.h"
#include "EEPROMHelper.h"
#include "BaroHelper.h"
#include "TrafficHelper.h"
#include "BatteryHelper.h"

#include "EasyLink.h"
#include "Protocol_UAT978.h"

#include <uat.h>
#include <fec/char.h>
#include <fec.h>
#include <uat_decode.h>

//#define DEBUG_UAT

#define isValidFix()      isValidGNSSFix()

EasyLink_RxPacket rxPacket;
extern EasyLink myLink;
extern FreqPlan RF_FreqPlan;

ufo_t ThisAircraft;

hardware_info_t hw_info = {
  .model    = DEFAULT_SOFTRF_MODEL,
  .revision = 0,
  .soc      = SOC_NONE,
  .rf       = RF_IC_NONE,
  .gnss     = GNSS_MODULE_NONE,
  .baro     = BARO_MODULE_NONE,
  .display  = DISPLAY_NONE
};

#if defined(DEBUG_UAT)
#include <xdc/std.h>

#include <xdc/runtime/System.h>
#include <xdc/runtime/Memory.h>
#include <xdc/runtime/Types.h>

#include <ti/sysbios/BIOS.h>
#include <ti/sysbios/knl/Task.h>
#include <ti/sysbios/utils/Load.h>
#include <ti/sysbios/hal/Hwi.h>

static void printUtilization()
{
    xdc_UInt i;
    Memory_Stats memStat;
    Hwi_StackInfo hwiStackStat;
    Load_Stat loadStat;
    Task_Handle tsk;
    float idleLoad;
    uint32_t idleLoadInt, idleLoadFrac;

    /* collect current stats */
    Load_update();

    /* use time NOT spent in idle task for Total CPU Load */
    Load_getTaskLoad(Task_getIdleTask(), &loadStat);
    idleLoad = 100.0 - 100.0*(float)loadStat.threadTime/(float)loadStat.totalTime;
    idleLoadInt = idleLoad;
    idleLoadFrac = 10.0*idleLoad - 10.0*idleLoadInt;

    Serial.write("Total CPU Load: ");
    Serial.print(idleLoadInt);
    Serial.print(".");
    Serial.println(idleLoadFrac);
    Serial.println("");
#if 0
    /* collect stats on all statically Created tasks */
    Serial.println("Task info:");
    for (i = 0; i < Task_Object_count(); i++) {
        tsk = Task_Object_get(NULL, i);
        printTaskInfo(tsk);
    }

    /* collect stats on all dynamically Created tasks */
    tsk = Task_Object_first();
    while (tsk) {
        printTaskInfo(tsk);
        tsk = Task_Object_next(tsk);
    }
    Serial.println("");
#endif
    Hwi_getStackInfo(&hwiStackStat, TRUE);
    Serial.print(F("Hwi stack usage: "));
    Serial.print(hwiStackStat.hwiStackPeak);
    Serial.print("/");
    Serial.println(hwiStackStat.hwiStackSize);
    Serial.println("");

    Memory_getStats(NULL, &memStat);
    Serial.print(F("Heap usage: "));
    Serial.print(memStat.totalSize - memStat.totalFreeSize);
    Serial.print("/");
    Serial.println(memStat.totalSize);
}
#endif /* DEBUG_UAT */

static bool UAT_Receive_Sync()
{
  // rxTimeout is in Radio time and needs to be converted from miliseconds to Radio Time
  rxPacket.rxTimeout = EasyLink_ms_To_RadioTime(2000);

  // Turn the receiver on immediately
  rxPacket.absTime = EasyLink_ms_To_RadioTime(0);

  EasyLink_Status status = myLink.receive(&rxPacket);

  if (status == EasyLink_Status_Success) {

#if defined(DEBUG_UAT)
    Serial.print("Packet received with length ");
    Serial.print(rxPacket.len);
    Serial.print(" RSSI ");
    Serial.print(rxPacket.rssi);
#if 0
    Serial.println(" and value:");
    Serial.println(Bin2Hex((byte *) rxPacket.payload, rxPacket.len));
#else
    Serial.println();
#endif
#endif

    rx_packets_counter++;

    return(true);
  } else {
#if defined(DEBUG_UAT)
    Serial.print("Error receiving packet with status code: ");
    Serial.print(status);
    Serial.print(" (");
    Serial.print(myLink.getStatusString(status));
    Serial.println(")");
#endif
    return(false);
  }
}

static bool UAT_receive_complete  = false;
static bool UAT_receive_active    = false;

void UAT_Receive_callback(EasyLink_RxPacket *rxPacket_ptr, EasyLink_Status status)
{
  UAT_receive_active = false;

  if (status == EasyLink_Status_Success) {
    memcpy(&rxPacket, rxPacket_ptr, sizeof(rxPacket));
    UAT_receive_complete  = true;
  }
}

static bool UAT_Receive_Async()
{
  bool success = false;
  EasyLink_Status status;

  if (!UAT_receive_active) {
    status = myLink.begin(EasyLink_Phy_Custom);

#if defined(DEBUG_UAT)
    if (status != EasyLink_Status_Success) {
      Serial.println(F("myLink.begin(EasyLink_Phy_Custom) failure."));
    }
#endif

    status = myLink.receive(&UAT_Receive_callback);

    if (status == EasyLink_Status_Success) {
      UAT_receive_active = true;
    }
  }

  if (UAT_receive_complete == true) {

    success = true;
    UAT_receive_complete = false;

    rx_packets_counter++;
  }

  return success;
}

#define UAT_Receive UAT_Receive_Async

void setup() {
  hw_info.soc = SoC_setup(); // Has to be very first procedure in the execution order

  Serial.begin(STD_OUT_BR, SERIAL_OUT_BITS);

  Serial.println();
  Serial.print(F(SOFTRF_IDENT));
  Serial.print(SoC->name);
  Serial.print(F(" FW.REV: " SOFTRF_FIRMWARE_VERSION " DEV.ID: "));
  Serial.println(String(SoC->getChipId(), HEX));
  Serial.println(F("Copyright (C) 2015-2020 Linar Yusupov. All rights reserved."));
  Serial.flush();

  EEPROM_setup();

  settings->mode = SOFTRF_MODE_BRIDGE;

  SoC->Button_setup();

  ThisAircraft.addr = SoC->getChipId() & 0x00FFFFFF;

  hw_info.display = SoC->Display_setup();

  hw_info.rf = RF_setup();

#if defined(DEBUG_UAT)
  Serial.print(F("SPI radio ID: "));
  Serial.println(hw_info.rf);
#endif

  if ( hw_info.rf != RF_IC_CC13XX ||
      (hw_info.rf == RF_IC_CC13XX && settings->rf_protocol != RF_PROTOCOL_ADSB_UAT)) {
    init_fec();
  }

  hw_info.gnss = GNSS_setup();

  Serial.print(F("Protocol: "));
  Serial.println(
    settings->rf_protocol == RF_PROTOCOL_LEGACY ? legacy_proto_desc.name :
    settings->rf_protocol == RF_PROTOCOL_OGNTP  ? ogntp_proto_desc.name  :
    settings->rf_protocol == RF_PROTOCOL_P3I    ? p3i_proto_desc.name    :
    settings->rf_protocol == RF_PROTOCOL_FANET  ? fanet_proto_desc.name  :
    "UNK"
  );

  Serial.print(F("GNSS: "));
  Serial.println(GNSS_name[hw_info.gnss]);

  Battery_setup();

  /*
   * Display 'U' (UAT) on OLED for Rx only modes.
   * Indicate Tx protocol otherwise
   */
  ThisAircraft.protocol = settings->rf_protocol;

  Serial.print(hw_info.rf == RF_IC_CC13XX ? F("Single") : F("Dual"));
  Serial.println(F(" radio bridge mode."));

  RF_loop();

  Serial.println(F("Listening..."));

  SoC->WDT_setup();
}

void loop() {

  GNSS_loop();

  if (hw_info.rf != RF_IC_CC13XX) {
    RF_loop();
  }

  bool success = UAT_Receive();

  if (success) {

    int rs_errors;
    ThisAircraft.timestamp = now();

    int frame_type = correct_adsb_frame(rxPacket.payload, &rs_errors);

    if (frame_type != -1 &&
        uat978_decode((void *) rxPacket.payload, &ThisAircraft, &fo) ) {
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

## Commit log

2020-07-22 3D printable STL files of SoftRF Lora32 enclosure
    [SoftRF-Lora32-case-top.stl, SoftRF-Lora32-case.stl]
2020-07-30 fix bug with setting unused pin for rpi
